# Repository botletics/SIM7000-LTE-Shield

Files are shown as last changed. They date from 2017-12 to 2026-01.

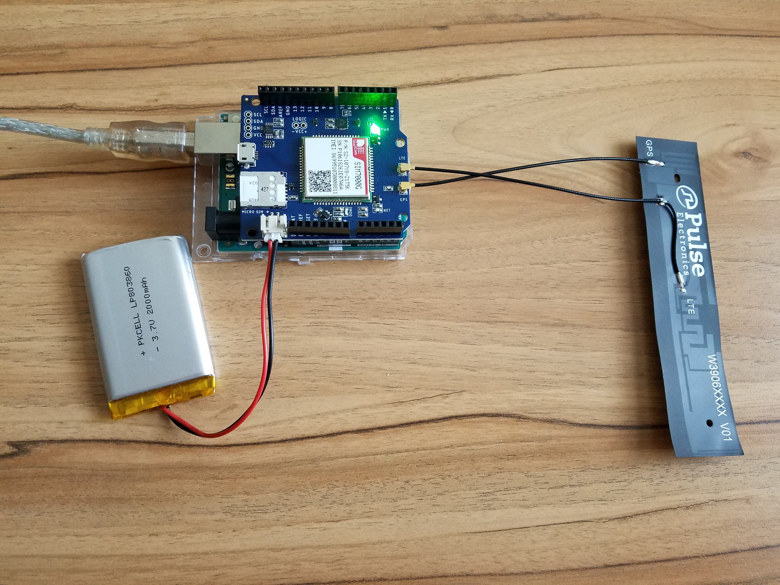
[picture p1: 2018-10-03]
Media/SIM7000 Shield v5 Complete Setup.jpg

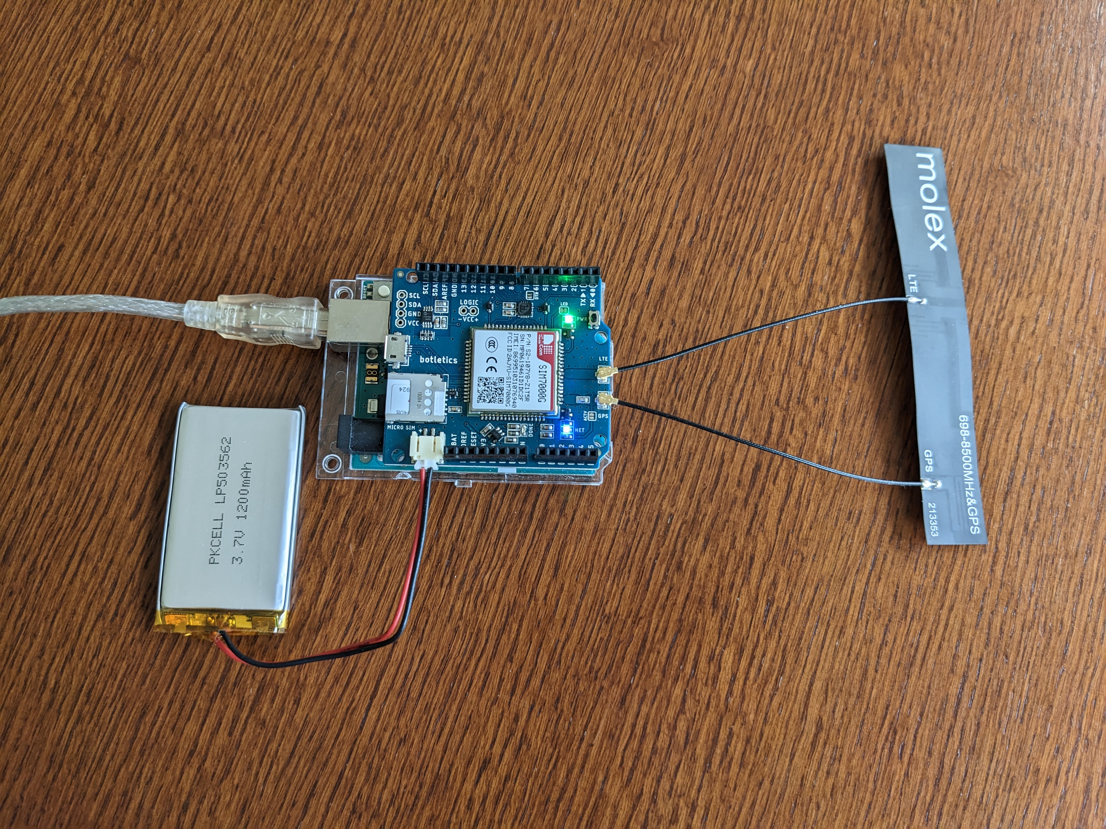
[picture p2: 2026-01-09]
Media/SIM7000 Arduino Assembly v6.jpg

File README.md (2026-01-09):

## Overview
This shield uses SIMCOM's SIM7000-series module, a low-power cellular module that supports LTE CAT-M1 and NB-IoT technology and integrated multi-GNSS (GPS, GLONASS and BeiDou/Compass, Galileo, QZSS standards) for location tracking. The shield also includes a high-accuracy I2C temperature sensor for IoT monitoring applications.

- [Buy shield on Amazon](http://a.co/d/eQ2l2TL)
- [Step-by-step wiki](https://github.com/botletics/SIM7000-LTE-Shield/wiki)
- [Arduino library with example code](https://github.com/botletics/Botletics-SIM7000) 
- [Botletics community forum](https://forum.botletics.com/) 

All PCB design files and hardware are released under the [Creative Commons Attribution Share Alike 4.0 license](https://choosealicense.com/licenses/cc-by-sa-4.0/).

All other software is released under the [GNU General Public License v3.0](https://choosealicense.com/licenses/gpl-3.0/).

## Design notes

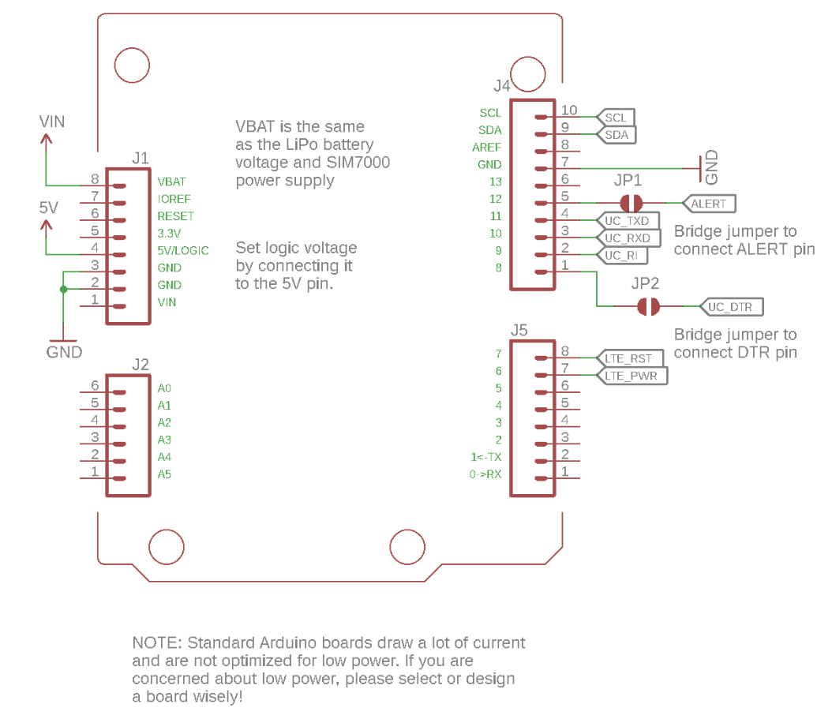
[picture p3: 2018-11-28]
Media/SIM7000 Shield Pinouts v6.PNG

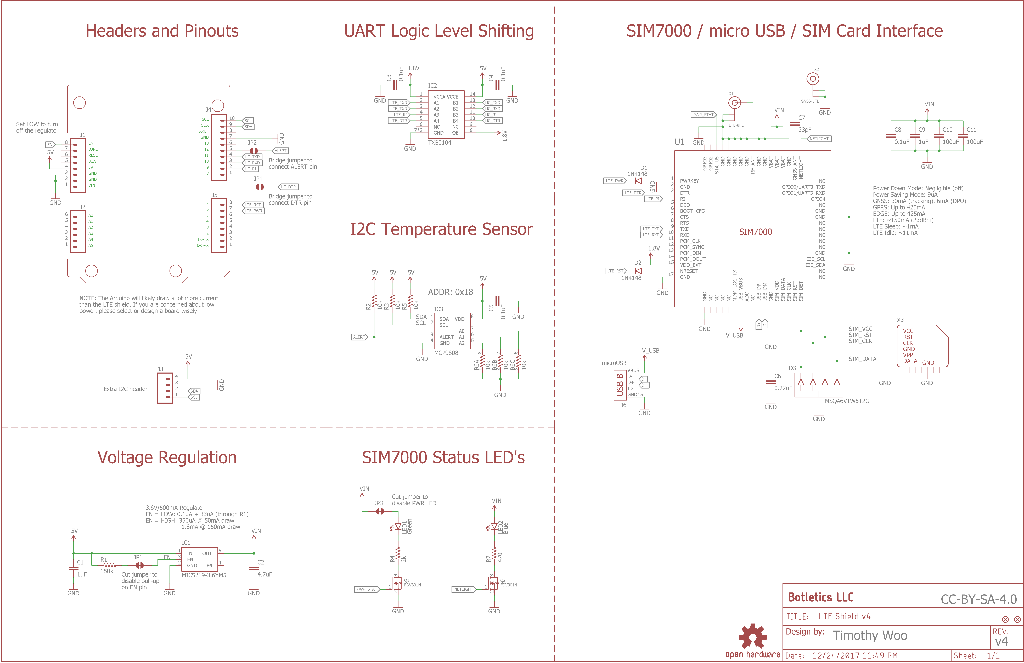
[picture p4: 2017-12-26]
Media/SIM7000 Shield Schematic v4.png

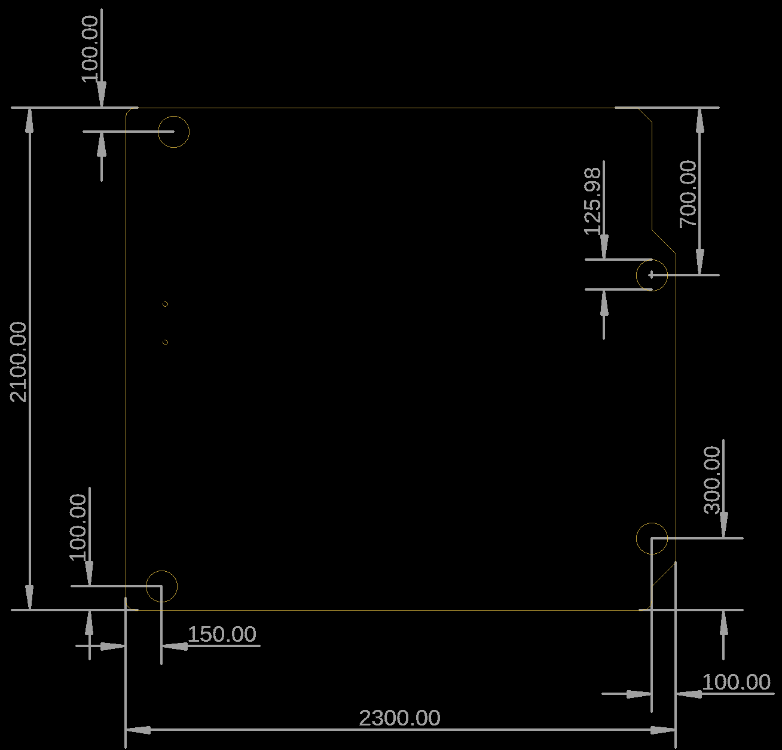
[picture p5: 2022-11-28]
Schematics/Board Dimensions.png

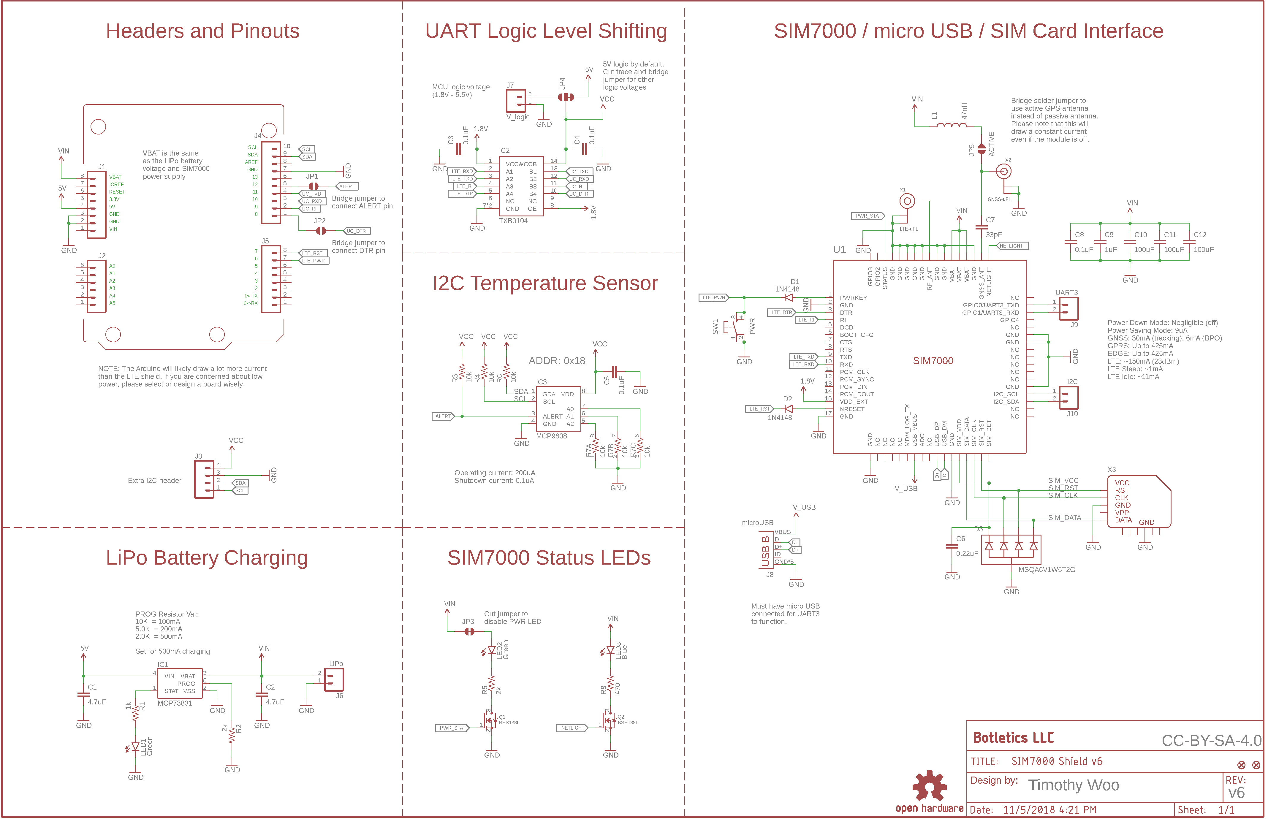
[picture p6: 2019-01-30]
Schematics/SIM7000 Shield Schematic v6.png

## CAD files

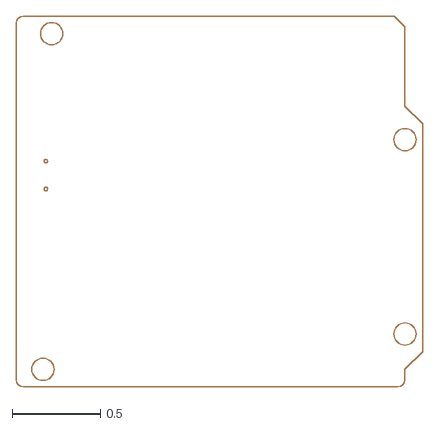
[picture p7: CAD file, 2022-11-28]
Schematics/SIM7000 Shield v6.dxf
2.30 x 2.10

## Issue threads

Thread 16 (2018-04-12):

Add support to upload firmware properly to solve IMEI issue

bengchet, 2018-04-12:
Hi,

First of all I would like to say your project is great, I love it. Here is some experience I did some firmware upgrade and I would like to share it.

I remembered I bought SIM7000E module before June 2017 and the module firmware is not very updated. So many AT command stated in manual can't be used. Been followed your guide on firmware update tool, I found that IMEI on module was missing after firmware upgrade.

To solve this, you will need restore QCN file attached follow the instruction under section **How to update xQCN file if necessary** in _How to update SIM7000 FW version with QPST.pdf_. The QCN file is standard and works for all SIM7000 series. Then run AT+SIMEI=_your IMEI number_. You can find IMEI number on top of SIM7000 module. Hope it helps.

[MDM9206_SIM7000E_P1.02_20180118.xqcn.zip](https://github.com/botletics/SIM7000-LTE-Shield/files/1902242/MDM9206_SIM7000E_P1.02_20180118.xqcn.zip)

** Better to confirm with SIMCOM engineer if the file works for all SIM7000.

botletics, 2018-04-12:
Thanks for your feedback! I will look into this.

gmgaston, 2019-02-27:
While running the IOT_Example provided, it runs down to the point where it tries to get the IMEI and then freezes.   I looked at the Adafruit_FONA.cpp file that is supplied on this github site.  It looks like it is expecting a 15 character IMEI but the IMEI on my Hologram SIM is 19 characters long.  I tried to adjust both the .ino and the .cpp file but still doesn't work.  I might not have done the adjustments correctly.
Any help to get my SIM7000-LTE-Shield working will be appreciated.
Thanks
Greg

adam6806, 2019-02-28:
I just added a ticket before I saw this comment from @gmgaston I'm having the exact same issue. I'm going to see if I can make the adjustment to the code as well but I would definitely appreciate a fix here. It is strange that the LTE demo worked perfectly but the iot example isn't. Wouldn't the both use the same library?

gmgaston, 2019-02-28:
I may have been mistaken about the length of the IMEI. I at first thought the IMEI was the 19 digit number on the hologram SIM card but that is not correct.

I do stand by my comment that I still can't get past where the IOT _Example tries to fetch the IMEI. I just hangs there.
The LTE_Demo does work OK.

Thanks
Greg

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

adam6806, 2019-02-28:
@gmgaston why don't we move this over to my issue then instead of this closed one. I did come to the same conclusion about the imei length. One other thing I noticed is that the lte demo has a reply buffer array and the iot example does not. reply buffer is used in that method. maybe there's something there.

gmgaston, 2019-02-28:
Adam:
OK. I don't know much about the issues blog. I just found it when I did a Google search for botletics/SIM7000-LTE-Shield and IMEI.

I will be spending some time on this in next few days. If I find something I'll let you know ..

Thanks
Greg

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

adam6806, 2019-02-28:
@gmgaston Link to the issue is here. If you find anything please post there. https://github.com/botletics/SIM7000-LTE-Shield/issues/75

botletics, 2019-03-04:
Make sure your board has a LiPo battery connected to it, and with proper polarity (red wire on the left side of the connector when you plug it in). Usually weird characters in serial monitor means there's a power issue.

hasikp1, 2020-06-30:
@botletics do you have the SIM7000C firmware with you? I used the waveshare SIM7000C firmware but it shows as B08SIM7000.
@bengchet I used the method you mentioned and restored a IMEI of SIM7000E it was successfull, but when I used it in the above mentioned SIM7000C firmware shows as B08SIM7000E. Do you have a qcn for SIM7000C

Closed 2018-06-04.

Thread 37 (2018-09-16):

Couldn't find FONA

aggounix, 2018-09-16:
I added the library and I uploaded the library but now I have another issue in the port monitor : Couldn't find FONA
I am using Hologram Sim card

botletics, 2018-09-16:
It's probably because you're using different hardware. Please keep your posts under the same issue and unfortunately I can't help everyone trying to use this library with their own hardware. [Look here if you want the official Botletics SIM7000 shield kit](https://www.botletics.com/products/sim7000-shield)

aggounix, 2018-09-17:
I bought the the same 7000E shield in the tutorial from botletics and using it with your tutorial here:
https://www.hackster.io/botletics/real-time-2g-3g-lte-arduino-gps-tracker-iot-dashboard-01d471
With this library and no other hardware is used here

botletics, 2018-09-17:
The default initialization code doesn't wait for the module to turn on, so you have to press the Arduino's reset button after you see the green PWR LED for the SIM7000 the first time you start it up.

aggounix, 2018-09-22:
I think there is a probleme with the SIM7000 because the PWR LED is never green (the status LED in [Shield pinout.](https://cdn.instructables.com/F4D/3G87/JFIIS97S/F4D3G87JFIIS97S.LARGE.jpg))
May be it is a problem with the SIM7000 shield

botletics, 2018-09-22:
That won't cause a compile error though.

aggounix, 2018-09-22:
this is not a compile error, the code is televersed to arduino and during execution it couldn't find the fona and I think because the shield is not powered up
The Staatus LEd is not working at all

botletics, 2018-09-22:
Please email me at botletics@gmail.com so we can share images more easily.

aggounix, 2018-09-22:
Thanks  a lot, I just sent you the images to your mail

botletics, 2018-09-22:
Thanks. The issue is most likely because you didn't solder the headers onto the board at all, so they're not making connection.

aggounix, 2018-09-22:
How  can I solder the headers to the headers, it seems to me fragile I am afraid to break it, do you have images on how must be done

botletics, 2018-09-22:
Yes, please see [this wiki page](https://github.com/botletics/SIM7000-LTE-Shield/wiki/Assembly)

aggounix, 2018-09-22:
Should I do it with a soldering tool kit like this: https://learn.adafruit.com/adafruit-guide-excellent-soldering/tools

botletics, 2018-09-22:
You just need a soldering iron and solder. There are many options available online, like on Amazon.

aggounix, 2018-10-01:
Great News, I soldered the pins to the shield and I get the status LED turned ON, I tried the IOT_Example and after pressing arduino reset button, I get it work. Iget these message:

FONA is OK
Found SIM7000E (European)
	---> AT+GSN
	<--- xxxxxxxxxxxxxxxxxxx
Module IMEI: xxxxxxxxxxxxxxxxxxx
	---> AT+CGNSPWR?
	<--- +CGNSPWR: 0
	---> AT+CGNSPWR=1
	<--- OK
Turned on GPS!
	---> AT+CIPSHUT
	<--- SHUT OK
	---> AT+SAPBR=0,1
	**<--- ERROR**
Failed to disable GPRS!
	---> AT+CIPSHUT
	<--- SHUT OK
	---> AT+CGATT=1
	<---
Failed to enable GPRS, retrying...
	---> AT+CIPSHUT
	<---
	---> AT+CGATT=1
	<---

Is it normal to get error for enabling GPS and failing enabling GPRS

botletics, 2018-10-01:
Are you using a LiPo battery? Does the green "PWR" LED next to the module ever turn off when you try to enable data? Disabling data and getting an error is OK, but enabling afterwards should work as long as you're connected to the network.

aggounix, 2018-10-01:
I am using the usb connection to power the shield.  The "PWR" LED is always on. In the tutorial it is said the iot code must be able to send gps position to dweet normally. What am I doing wrong to not have the position on dweet

botletics, 2018-10-01:
The USB does not power the shield, as mentioned in the wiki. Please run the LTE_Demo sketch first and make sure you're connected to the network (use "n" command) and that everything else works (GPS, etc). Then you can move on to the IoT_Example sketch.

aggounix, 2018-10-01:
When I use th en command in LTE_Example I get this message:
Network status 2: Not registered (searching)
I am using a hologram sim card

botletics, 2018-10-01:
That would explain why you can't enable data. Please see [this wiki page](https://github.com/botletics/SIM7000-LTE-Shield/wiki/Connecting-to-Network) on getting connected.

JetForce33, 2019-03-04:
Thank you!

mduiop, 2021-03-07:
I am using the SIM7000A module purchased from Amazon in the U.S..  I am attempting to run LTE_Demo on my Arduino Mega 2560.  I have a 3.7v battery connected to the battery terminal.  I am using the provided headers soldered onto the module.  Activated Hologram SIM.  I set my vars as such:

// For SIM7000 shield
#define FONA_PWRKEY 6
#define FONA_RST 7
//#define FONA_DTR 8 // Connect with solder jumper
//#define FONA_RI 9 // Need to enable via AT commands
#define FONA_TX 1 // Microcontroller RX
#define FONA_RX 0 // Microcontroller TX
//#define T_ALERT 12 // Connect with solder jumper

When I run this code on the Arduino with the SIM7000A I get:

. . .
Timeout: No response to AT... last ditch attempt.
	---> AT
	<---
. . .
	---> ATE0
	<---
Couldn't find FONA

botletics, 2021-03-07:
The issue looks like it's because you changed the pin definitions. Please load the unaltered LTE_Demo sketch and see if it works.

mduiop, 2021-03-07:
> The issue looks like it's because you changed the pin definitions. Please load the unaltered LTE_Demo sketch and see if it works. By default the code uses software serial with pins 10 and 11 for UART.

OK, I could have sworn I did, but to "humor you" I decided to do that yet again.  Well, it works now, so thank you very much for the quick reply.  (If you detect sarcasm it is self-deprecating . . . not directed at you . . . mocking myself).

sagarchowdhury, 2021-04-24:
i am also getting the same error couldnt find fona

mduiop, 2021-04-24:
> i am also getting the same error couldnt find fona

Make sure you have reception, and don't change the pin definitions. That worked for me. I used the scripts unaltered and they worked.

sagarchowdhury, 2021-04-24:
> > i am also getting the same error couldnt find fona
>
> Make sure you have reception, and don't change the pin definitions. That worked for me. I used the scripts unaltered and they worked.

yes the the network led light is blinking after every 3 seconds, what i did differently is i used breadboard to connect the header with the module ,and connected each header pin with a jumper wire to the Arduino to simulate it like a shield ,do you think there may be loose connection because i didnt solder the header pins with the module

mduiop, 2021-04-24:
I'm no expert, but yes, that is a big possibility. Solder the header pins
and use it as a shield if you can. Requires a good connection.

On Fri, Apr 23, 2021, 11:03 PM sagar chowdhury ***@***.***>
wrote:

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

sagarchowdhury, 2021-04-24:
> I'm no expert, but yes, that is a big possibility. Solder the header pins and use it as a shield if you can. Requires a good connection.
> […](#)
> On Fri, Apr 23, 2021, 11:03 PM sagar chowdhury ***@***.***> wrote: i am also getting the same error couldnt find fona Make sure you have reception, and don't change the pin definitions. That worked for me. I used the scripts unaltered and they worked. yes the the network led light is blinking after every 3 seconds, what i did differently is i used breadboard to connect the header with the module ,and connected each header pin with a jumper wire to the Arduino to simulate it like a shield ,do you think there may be loose connection because i didnt solder the header pins with the module — You are receiving this because you commented. Reply to this email directly, view it on GitHub <[#37 (comment)](https://github.com/botletics/SIM7000-LTE-Shield/issues/37#issuecomment-826024235)>, or unsubscribe <https://github.com/notifications/unsubscribe-auth/ANFG5KMKQTHNTC2H47AKSGLTKIYGVANCNFSM4FVLNFPQ> .

one strange thing i noticed is i am getting replies at 9600 baud rate in com port but it should ideally be 115200 ,when i am changing to the 115200 i am not finding anything ,the serial monitor is blank

mduiop, 2021-04-24:
Yeah, I'm pretty sure the serial monitor has to be set to the same baud
rate set in the script.

On Fri, Apr 23, 2021, 11:15 PM sagar chowdhury ***@***.***>
wrote:

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

Closed 2018-09-16.

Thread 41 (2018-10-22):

Firmware update failed

robertgrochowski, 2018-10-22:
Hello,

I have installed all the drivers, no unknown devices appear in Windows Device Manager.
I also followed upgrade instructions step by step, checked everything few times but I still can't manage to update due to "ConnectServer failed1, Please repower 1 DUT" error.

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

Thanks in advance

botletics, 2018-10-22:
Hi there,

To aid in assisting you, what hardware are you using? Do you have a 3.7V LiPo battery connected? It may be that your device is shutting off when trying to update. Updating firmware requires a lot of power.

robertgrochowski, 2018-10-22:
Hi,

Thank you for fast reply. To be honest, I use another SIM700E shield (exactly DFRobot Shield NB) but the producer doesn't include information how to upgrade it. Only Your tutorial seems to be suitable.

I power it from power supply (12v through VIN) and the board works like a charm.

I have tried also your 2nd tutorial to upgrade it through QPST Tool but unfornatelly I run into difficulties because I couln't select port from the list (the list was empty). I tried to run as administartor, restart my PC and board as well but that didn't help. Do you have any suggestions?

Thanks in advance.

botletics, 2018-10-22:
Do you have any sort of indication that the module is turning off during the update process, especially right before it says to repower DUT?

botletics, 2018-10-22:
Could you show me a screenshot of what device manager looks like before you do the update? Go through literally each entry in device manager that's related to the SIM7000, right click, update driver, and point it to the drivers folder.

robertgrochowski, 2018-10-22:
Of course, I have done it for every SIM device.

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

botletics, 2018-10-22:
Hmm not sure, sorry.

lutfisan, 2018-11-16:
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

is it solve? i have same problem

robertgrochowski, 2018-11-16:
Unfortunately, no.

royallyovershoot, 2019-11-02:
Hey, @robertgrochowski I know it's more than a year late but I encountered the same exact problem with DFRobot and figured out how to fix it. Feel free to PM me since I this is a Botletics chain :)

robertgrochowski, 2019-11-02:
@royallyovershoot Thanks for letting know. Can you post your solution here? It will help others as well.

royallyovershoot, 2019-11-02:
Ok, there are two test points on the board (TP1 and TP2) shown on the attached snippet of the schematic. Those need to be shorted together during update, so using a soldering iron you can solder two pin headers and use a shunt to short them when you are updating the firmware and then remove the shunts when you're done with the update.

It's important to keep in mind that those two pins must be shunted before powering up the board.
I got to 100% but I got an error that it failed to back-up. But everything is working fine. This was included from the hardware design guide: [here](https://simcom.ee/documents/SIM7000x/SIM7000%20Hardware%20Design_V1.05.pdf)
On Page 20  under "Other interface" -> Boot_CFG it explains it.

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

madatr, 2019-11-19:
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

MAN, YOU ARE A GOD SEND!!!!!
I've been stuck on this for two weeks and was at giving up point.
Thank you for taking up time to share this.
and shame on manufacturers who don't share crucial information like this.

royallyovershoot, 2019-11-19:
@madatr Hah, I'm glad that it helped! It was a dick move from the manufacturers but hope you complete your project with ease now :)

hasikp1, 2019-11-19:
Hi, I have a SIM7000E module bought from aliexpress. It only have 7 pins as output, G-GND,R-RXD,T-TXD,K-PWRKEY,V-VCC,G-GND and S-SLEEP. I tried to update the firmware following the guide provided by @botletics. I also got the "QHSUSB_BULK" in device manager. Does this mean somehow I have to get boot_cfg and VDD_EXT shorted based on steps provided by @royallyovershoot. Is there any other alternatives?

madatr, 2019-11-20:
well... I can't tell you what to do exactly. The board i'm using has a USB connector provided with necessary hardware to facilitate that, the error/issue I had is that the update software wouldn't be able to switch the board to download mode so I had to force it using @royallyovershoot instructions.
I would recommend that you make sure that your board can communicate with the PC correctly first as the issue might be from that end.
btw, my board does not have the boot_cfg and vdd_ext as well, i just shorted the pins on the chip using a wire and had someone use the software to update it:
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

KerryRJ, 2020-06-11:
I have a waveshare NBT-IoT hat. I also got stuck at "waiting switch to download mode" and the QHSUSB_BULK device appeared in device manager. I just updated the driver in device manager from https://www.waveshare.com/wiki/File:SIM7X00-Driver.7z and the update process immediately continued.

hasikp1, 2020-06-15:
@madatr Are you using this module
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

semorem, 2020-09-16:
> I have a waveshare NBT-IoT hat. I also got stuck at "waiting switch to download mode" and the QHSUSB_BULK device appeared in device manager. I just updated the driver in device manager from https://www.waveshare.com/wiki/File:SIM7X00-Driver.7z and the update process immediately continued.

@KerryRJ hello there, i have the same issue that you did with the same hardware, but i already have the lastest dirvers installed. Did you just update the drivers? Did you do it during the firmware's update?

KerryRJ, 2020-09-16:
I updated the driver during the firmware update.

Kind Regards

Kerry Jones
Owning Member

Info-Overdrive cc
[IO Drive square logo - blue - small]

m. +27(0)612403717
e. kerry@iodrive.co.za<mailto:kerry@iodrive.co.za>
a. F3 Chief Mhlabunzima Rd., Pietermaritzburg, 3201

Website<http://www.iodrive.co.za/>        Email<mailto:kerry@iodrive.co.za>            IM<sip:kerry@iodrive.co.za>

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

semorem, 2020-09-16:
Thanks dude! It seems to be working!!!

BuiHao1996, 2020-10-30:
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

Could you send me your software to upload SIM 7600CE ?

MaffooClock, 2021-01-27:
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

When I got to this, I simply installed the driver (from the same folder as all the other drivers), and as soon as it finished, QDL resumed automatically.

VeselaHouba, 2021-04-16:
I know this thread is closed, but just for reference:
Using waveshare sim7000E

1. Blew off dust of my old Windows Laptop
1. Plugged the module to USB, didn't see any issues with power consumption
1. Installed drivers as described in https://github.com/botletics/SIM7000-LTE-Shield/wiki/USB-Drivers
1. Following upgrade guide https://github.com/botletics/SIM7000-LTE-Shield/wiki/Updating-Firmware
1. Upgrade hanged on something like "Waiting to switch to download mode"
1. Opened device manager, installed latest driver from https://www.waveshare.com/wiki/File:SIM7X00-Driver.7z
1. Update tool picked-up by itself and continued the installation until finish

kjm1102, 2023-12-29:
More than 2 years after the last post, I might get lucky?
I've got a 7080G with 1951B05sim7080 firmware that doesn't work too well but the downloader wants to load 1951B04sim7080 which is even older.
I'd like to upgrade it to 1951B07sim7080 that runs great in another 7080G but I can't figure out how to copy it from the modem it's in.
So I'm looking for a link to where I might get some 1951B07sim7080 firmware

eisaev, 2024-01-02:
@kjm1102 Have you tried this?
https://github.com/Xinyuan-LilyGO/LilyGo-T-PCIE/tree/master/update_simxxxx_firmware/1951B08SIM7080

kjm1102, 2024-01-02:
tnx for the links. I grabbed the 3 files that this wretched flasher I got from waveshare says it needs & copied them to a folder on an E drive to match the byzantine path it needs (there seems to be no way to edit the path) but the usual story, "computer says no". Can you see what I've missed from the attached? I'm new to modem flashing.
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

eisaev, 2024-01-03:
> tnx for the links. I grabbed the 3 files that this wretched flasher I got from waveshare says it needs & copied them to a folder on an E drive to match the byzantine path it needs (there seems to be no way to edit the path) but the usual story, "computer says no". Can you see what I've missed from the attached? I'm new to modem flashing. ![noexist](https://private-user-images.githubusercontent.com/92007731/293807827-1b56f12e-0dc4-461c-9699-e51dee20c9a8.jpg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)

The flasher expects that there will be more subfolders in the path. Increase the size of the flasher window to see the full path and try to create the required folder structure.

kjm1102, 2024-01-03:
tnx Evgeniy.  I finally got the firmware folders where the updater tool expects to find them.
1) At the beginning device manager shows 3 comports:
    SimTech HS-USB AT Port 9205 (COM27)
    SimTech HS-USB Diagnostics 9205 (COM29)
    Simtech HS-USB NMEA 9205 (COM28)
2) The tool starts on com 29, reads the imei & does a few other things then swaps to COM27
3) There is a USB disconnect & the 3 comports ABOVE vanish to be replaced Qualcom HS-USBQDLoader 9008 (com30)
4) The tool reconnects on COM30 but timesout waiting for prog_firehose_nand.elf which is definitely present in the folder
Any thoughts on what I could try next?

Closed 2018-10-22.

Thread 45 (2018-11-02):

Intermittent PWR issue

airy52, 2018-11-02:
The board seems to intermittently reset the power and the PWR LED on your sim7000A board board goes off. I am sometimes able to get the chip to connect to the verizon hologram network and issues the n or 1 command in the LTE_demo example. Sometimes I get ctreg 0,2 which is searching. But eventually the PWR LED resets and I am unable to get any further responses from AT commands until I hit the reset button on the arduino mega 2650 board to establish a connection with it again. When it connects to the network it seems to be pretty stable for a while, until I issue the G command for gprs. It then gets to the SAPBR command, or sometimes as far as this:
---> AT+SAPBR=1,1
	<--- OK
	---> AT+CIICR
	<--- +PDP: DEACT
But then the power resets and I am stuck unable to get a response again. When I first tried this a week ago I was able to reach the internet once or twice, after many failed attempts. I did not edit any of the code. I'm connected by USB power. The antenna is connected correctly and I have good signal. Any ideas?

botletics, 2018-11-02:
Sounds like you do not have a 3.7V LiPo battery, which is required. Please try that and it should work like a charm :)

Closed 2018-11-02.

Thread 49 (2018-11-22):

No PPP on UART with B05

Redferne, 2018-11-22:
Hi,

Just tried the B05 firmware but couldn't setup PPP over UART anymore:
```
-> AT+CGREG?
<- OK
-> AT+CGATT?
<- ..+CGATT: 1....OK..
-> AT+CPSI?.
<- +CPSI: LTE CAT-M1,Online,240-XX,0x0086,7681025,0,EUTRAN-BAND1,1925,2,2,0,0,125,0 OK
-> AT+CGPADDR.
<-  +CGPADDR: 1,10.41.136.51 OK
-> AT+CGNAPN.
<- +CGNAPN: 1,"xxx.com.xx" OK
-> ATD*99***1#.
<- ERROR
```

I had to downgrade to B03 again:
```
-> ATD*99***1#.
<- CONNECT 150000000
```
And PPP over UART works fine again. Any ideas?

botletics, 2018-11-22:
I'm assuming you're using SIM7000E? Sorry, I really have no idea because I only use SIM7000A and SIM7000G here in the US.

supersjimmie, 2018-12-11:
I  have heard there is a B06 firmware coming (for my sim7000e).
They gave an early version to me because an issue with the NMEA port, but that caused other issues. So you might wait or even ask Waveshare for the B06 firmware release.

korseby, 2019-02-18:
Have you found a solution yet?

I have the same problem using the Waveshare HAT (https://www.waveshare.com/wiki/SIM7000E_NB-IoT_HAT).

I've updated to the B06 Firmware from their website but getting the same error when using ATD.

supersjimmie, 2019-02-18:
This was the reply then:
If you send AT command to get GPS data via USB interface, USB interface will be hang-up as soon as GPS is enabled, because GPS data is outputed from USB port by default. We doubt that the problem you face is caused by this reason. Did you try to change the NMEA output?

xmichaelx, 2019-03-17:
@korseby @supersjimmie Same issue here. Any good news on this? I've managed to get GPS working and establish TCP connection using sample programs  but with ppp no luck so far.

I'm using these [instructions](https://www.waveshare.com/wiki/SIM7000E_NB-IoT_HAT). Do you have any other recommendation for similar board that works better with ppp?

korseby, 2019-03-18:
As far as I understand it, linux handles the IoT devices using a different protocol. I tried to play around with `usb_modeswitch` and `modprobe usbserial` and tried to bring linux to recognize the Waveshare board as `wwan` interface (using the IoT protocols), but without luck so far. In theory, the `ModemManager` is supposed to do all that, but it seems to be broken in the current Raspbian release.

Below is what I have tried as far as I remember it. As many of the config option have changed because Raspbian switched to `systemd` I do not know anymore how to properly configure network interfaces with terminal commands... That s****s and there is no proper documentation around how the commands are with IoT devices ...

Editing /etc/network/interface.d/wwan0 (this has become obsolete) ...
```
iface wwan0 inet dhcp
   wwan_apn  "APN"
```

Set the APN and bring up the IoT connection manually (you can also do this using minicom -D /dev/ttyS0) ...
```
echo -ne 'AT^NDISDUP=1,1,"APN"\n\r' > /dev/ttyS0
echo -ne 'AT+CIPCSGP=1,"APN","",""' > /dev/ttyS0
echo -ne 'AT+CGDCONT=1,"IP","APN"' > /dev/ttyS0
echo -ne 'AT+CNACT=1' > /dev/ttyS0
echo -ne 'AT+CSTT="APN"\n\r' > /dev/ttyS0
echo -ne 'AT+CIICR\n\r' > /dev/ttyS0
```

Bringing up wwan0 manually ...
```
ifconfig wwan0 up
dhclient wwan0
netstat -rn
ip route add default via x.x.x.x dev wwan0
```

Playing around with ModemManager and/or the CLI ...
```
mmcli -L
nmcli c add type gsm wwan0 /dev/usbS0 con-name APN apn APN
nmcli r wwan0 on
```

Maybe you can figure it out better than I do :)

Some other people had similar problems ...
https://blog.soracom.io/beginners-guide-to-iot-cellular-connectivity-on-raspberry-pi-and-linux-devices-55d4f7489adf
https://docs.ubuntu.com/core/en/stacks/network/network-manager/docs/configure-cellular-connections
https://www.linuxquestions.org/questions/linux-wireless-networking-41/help-using-3g-usb-dongle-through-wwan-interface-rather-than-ppp-4175537653/

Good luck.

xmichaelx, 2019-03-18:
@korseby Thank you, at the very least you've given me hope :)

xmichaelx, 2019-03-18:
I've  tried using *wvdial* with following config (SIM7000 plugged in via USB):
```
[Dialer Defaults]
Init1 = ATZ
Init2 = ATQ0 V1 E1 S0=0 &C1 &D2
Init3 = AT+CGDCONT=1,"IP","plus"
Modem Type = Analog Modem
ISDN = 0
Phone = *99#
Modem = /dev/ttyUSB2
Username = blank
Password = blank
Baud = 9600
```

and the output from wvdial:

```
--> WvDial: Internet dialer version 1.61
--> Cannot set information for serial port.
--> Initializing modem.
--> Sending: ATZ
OK
--> Sending: ATQ0 V1 E1 S0=0 &C1 &D2
ATQ0 V1 E1 S0=0 &C1 &D2
OK
--> Sending: AT+CGDCONT=1,"IP","plus"
AT+CGDCONT=1,"IP","plus"
OK
--> Modem initialized.
--> Sending: ATDT*99#
--> Waiting for carrier.
ATDT*99#
CONNECT 150000000
--> Carrier detected.  Waiting for prompt.

--> Connected, but carrier signal lost!  Retrying...
--> Sending: ATDT*99#
--> Waiting for carrier.
--> Timed out while dialing.  Trying again.
--> Sending: ATDT*99#
--> Waiting for carrier.

```

and LED on my SIM7000E-NB-IoT-HAT starts starts repeatedly flashing as if the device stoppped responding and indeed that's what it looks like.

Reissuing wvdial gives:

```
--> WvDial: Internet dialer version 1.61
--> Cannot set information for serial port.
--> Initializing modem.
--> Sending: ATZ
--> Sending: ATQ0
--> Re-Sending: ATZ
--> Modem not responding.
```

so it looks like the serial port stopped responding altogether.

I'm kinda disappointed - I've sort of managed to get GPS signal when hat is connected to GPIO pins and also managed to get the samples working, but getting working ppp/wwan0 seems to be impossible.

Anyways @korseby thanks for help. Do you have any recommendations for alternative that you know works well on raspberry?

qsun, 2019-07-22:
It looks like I've same issue with B05 firmware on SIM7000E, but I could not confirm it's working with B03.

korseby, 2019-07-22:
Latest waveshare firmware includes some additions, but could not read about fixes... It could be worth a try though.

https://www.waveshare.com/w/upload/6/60/NDA_SIM7000E_Firmware_Release_Note.pdf

qsun, 2019-07-23:
@korseby

Thank you very much for your reply, and I can confirm B08 firmware is working fine.

```
AT+GMR
Revision:1351B08SIM7000E

OK
AT+CGREG?
+CGREG: 0,2

OK
AT+CGREG?
+CGREG: 0,1

OK
AT+CPSI?
+CPSI: LTE CAT-M1,Online

OK
AT+CGPADDR
+CGPADDR: 1,10.118.51.20
+CGPADDR: 13,0.0.0.0

OK
AT+CGNAPN
+CGNAPN: 1,"telstra.m2m"

OK
ATD*99***1#
CONNECT 150000000
```

qsun, 2019-07-23:
@korseby

Thank you very much for your reply, and I can confirm B08 firmware is working fine.

```
AT+GMR
Revision:1351B08SIM7000E

OK
AT+CGREG?
+CGREG: 0,2

OK
AT+CGREG?
+CGREG: 0,1

OK
AT+CPSI?
+CPSI: LTE CAT-M1,Online

OK
AT+CGPADDR
+CGPADDR: ~~~
+CGPADDR: ~~~
OK
AT+CGNAPN
+CGNAPN: 1,"telstra.m2m"

OK
ATD*99***1#
CONNECT 150000000
```

botletics, 2019-07-23:
I guess I can close this now?

Closed 2019-07-23.

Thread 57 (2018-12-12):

Commands echo back instead of OK

supersjimmie, 2018-12-12:
At several different point, sometimes the program goes into a loop, because the sim7000 starts to repeat the commands instead of replying with OK.

This happens at more places, during GPS, during Connect to cell, and more.
Looks like:
```
Failed to get GPS location, retrying...
	---> AT+CGNSINF
	<--- AT+CGNSINF
Failed to get GPS location, retrying...
	---> AT+CGNSINF
	<--- AT+CGNSINF
```

Or:
```
Failed to connect to cell network, retrying...
	---> AT+CGREG?
	<--- AT+CGREG?
Network status 0: Not registered
Failed to connect to cell network, retrying...
	---> AT+CGREG?
	<--- AT+CGREG?
```
I tried to flush the fonaSS, send an extra AT, wait a while, I cannot find why and I cannot find how to get out of this strange state...

botletics, 2018-12-12:
Did you set **ATE1** which enables echo? For example, if you were trying to send AT commands via USB and set ATE1 so that you can see the stuff you're typing.

botletics, 2018-12-12:
To disable, set **ATE0** which should also be set during module initialization in the LTE_Demo code.

supersjimmie, 2018-12-12:
Yes it does ATE0 at the beginning.
Here's some more:

```
Attempting to open comm with ATs
	---> AT
	<--- OK
	---> ATE0
	<--- OK
	---> ATE0
	<--- OK
	---> ATI
	<--- SIM7000E R1351

OK

	---> AT+CPMS="SM","SM","SM"
	<--- +CPMS: 0,0,0,0,0,0
FONA is OK
Found SIM7000E (European)
	---> AT+GSN
	<--- 8652340xxxx
Module IMEI: 8652340xxxx
	---> AT+CFUN=1
	<--- OK
	---> AT+CGDCONT=1,"IP","cdp.iot.t-mobile.nl"
	<--- OK
	---> AT+CGREG?
	<--- +CGREG: 0,5
Network status 5: Registered roaming
Connected to cell network!
	---> AT+CGNSPWR=1
	<--- OK
Turned on GPS!
	---> AT+CGNSINF
	<---
Failed to get GPS location, retrying...
	---> AT+CGNSINF
	<--- +CFUN: 1
Failed to get GPS location, retrying...
	---> AT+CGNSINF
	<--- AT+CGNSINF
Failed to get GPS location, retrying...
	---> AT+CGNSINF
	<--- AT+CGNSINF
```

As you can see, there is also a strange thing happening here:
```
---> AT+CGNSINF
	<--- +CFUN: 1
```
Like it comes back with something from an earlier command.
Then it starts to malfunction...

botletics, 2018-12-12:
Looks like your shield is powering off. Messages like "+CFUN: 1" are usually displayed shortly after it boots up. Please make sure you are using a 3.7V LiPo battery with the shield.

supersjimmie, 2018-12-12:
I have a newer version of the shield, it lacks things like the PWR push button and also the possibility to add the LiPo. When I asked them about it, Waveshare told me that I don't need that.... (looking at the PCB, there is no regulator for the LiPo too)

It works fine about 9 out of 10 times.

botletics, 2018-12-12:
Newer version? The newest version of the Botletics SIM7000 shield has a LiPo battery connector. If you're using something else that sorry, I don't know.

botletics, 2018-12-12:
Sounds like Waveshare didn't fully test their product then. From what you're experiencing, the module is definitely shutting down. If there's a power indicator LED you should be able to see it shut down. Also, try enabling GPS. I think the module will most certainly shut off because GPS draws another 30mA of current.

supersjimmie, 2018-12-12:
LOL, they've also changed the Power-LED. It's always on, regardless of the actual state of the module...
(they also changed the PWR-pin behavior, but I am able to do the power down, while the LED stays on)
I guess the only way to save some extra current during power down, is to kick that LED off the PCB...
They only way so actually see the power down is via the current draw and the activity LED that really stops blinking. (and the module stops accepting AT commands when I test it)

There is a large 1000uF capacitor on the board, which they say should fix it.
I will try to add an additional tantalum capacitor, which is also very helpful with power-peaking modules likes esp8266's. (tantal's are better for this kind of stabilization)

But just to clarify things a little bit, this is actually not exactly the arduino shield that you use, it's really a module made for the raspberry pi. It's had the same features (like the powerbutton) in the recent past, but because some people had trouble powering it on, they decided to change it.  I had very recent contact with them by e-mail about several of those changes and some issues with the B05 firmware.
They just keep saying that "The SIM7000E is updated", every time I complain.

botletics, 2018-12-12:
Yea I understand you're using the Waveshare Raspberry Pi HAT instead of the shield I created (the Botletics one). Sorry, not much I can do to help there lol. I'm a firm believer that product support should come from the people selling it  :)

supersjimmie, 2018-12-13:
Sure, now we know that it's caused by the lack of lipo support, it's up to the sellers.
But you helped me a lot by finding out that the device was restarting, before that I had no clue...

Fredovsky, 2019-02-13:
@supersjimmie did you manage to solve/identify the issue ? I got the exact same problem, AT response is either : empty; echoes the command; or rarely I have the odd +CFUN: 1. I'm powering up through a separate supply able to handle high load so I don't think power is an issue here.

I know this is not related to Botletics as I'm using the Waveshare piHat board, but curious if others have resolved this problem.

Thanks

supersjimmie, 2019-02-13:
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

@Fredovsky
After a lot of mails, I got the message that "the engineer went on holiday", then nothing... That was about a month ago. I think I will send them a mail to ask if the engineer ever came back.

supersjimmie, 2019-02-14:
@Fredovsky  they now replied that it is solved in firmware: https://www.waveshare.com/wiki/File:1351B06SIM7000E.rar
But I told them last december that I already use that. Perhaps you can check to be sure?

Fredovsky, 2019-02-16:
Thanks I'll try again next week if I can flash the new firmware but last I tried the QPST tool was returning a "DUT 1" (not sure) error. I'll let you know ! Thanks.

Fredovsky, 2019-02-18:
Ok so I updated to the B06 firmware. Problem remains the same. I noticed I don't have any problems when I type the AT commands manually through serial on the Sim7000 USB port (using Putty for exemple).

When using the Arduino and the Fona library, it starts echoing or giving blank replies after 5 or 6 commands...

botletics, 2019-02-24:
Mhmm sorry I'm not sure what is happening. It should find it and communicate right away.

Closed 2018-12-12.

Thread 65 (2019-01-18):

Connecting to hardware serial

ammarqs, 2019-01-18:
Timothy,

I am using the arduino mega and noticed that to use the tcpsend, it is better to use the hardware serial for better baud rates. To set up the hardware serial, please confirm the following changes to the program.

1. Remove all softwareSerial fonass function definitions.
2. in the modulesetup function, change the fonass to Serial3 (or whatever serial port the system is connected to)
3. Change the wiring from D10 to 15 on mega, and D11 to 14 on mega.

botletics, 2019-01-18:
With Arduino Mega if you change the pins from the default D10/D11 software serial pins, the shield won't be directly plug-in compatible.

I am aware of hardware serial allowing faster baud rates, and this is mentioned in a couple places in the Github wiki as well. However, I've had no issues with 9600 baud rate on software serial and it's good enough for most people's applications.

ammarqs, 2019-01-18:
Its ok if its not direct plugin compatible. We will be designing our own controller board to fit this shield.
So the pins D10/D11 are software serial on the shield? it wont work if i connect the D10 to 15 and D11 to 14 on mega. ?

Right, it is. but when trying to send a small image over through the tcpsend function, it takes more than 30secs to a minute to send a 5kb image.

I changed the program to this, and it says couldn't connect:
`Serial.begin(115200);
 Serial3.begin(115200); // Default SIM7000 shield baud rate
  if (! fona.begin(Serial3)) {
    Serial.println(F("Couldn't find FONA"));
    while(1); // Don't proceed if it couldn't find the device
  }
`
It returns back could not find FONA.

botletics, 2019-01-18:
Check out lines 77-89 of the [LTE_Demo sketch](https://github.com/botletics/SIM7000-LTE-Shield/blob/master/Code/examples/LTE_Demo/LTE_Demo.ino)

botletics, 2019-01-18:
[And this](https://github.com/botletics/SIM7000-LTE-Shield/wiki/Pinouts#hardware-serial-note)

botletics, 2019-01-18:
For the code, the [SAMD_LTE_Demo sketch](https://github.com/botletics/SIM7000-LTE-Shield/blob/master/Code/examples/SAMD_LTE_Demo/SAMD_LTE_Demo.ino) will be particularly helpful. It uses hardware serial.

ammarqs, 2019-01-18:
Thank you. that helped. But i am still getting the same couldnt connect error:

`

// Hardware serial is also possible!
HardwareSerial *fonaSerial = &Serial3;

void setup(){
  Serial.begin(115200);
 powerOn(); // Power on the module
  moduleSetup();

void moduleSetup() {
  // Note: The SIM7000A baud rate seems to reset after being power cycled (SIMCom firmware thing)
  // SIM7000 takes about 3s to turn on but SIM7500 takes about 15s
  // Press reset button if the module is still turning on and the board doesn't find it.
  // When the module is on it should communicate right after pressing reset
  Serial3.begin(115200); // Default SIM7000 shield baud rate
 // fonaSerial->begin(115200);
 // Serial.println(F("Configuring to 115200 baud"));
 // Serial3.println("AT+IPR=115200"); // Set baud rate
 // delay(100); // Short pause to let the command run
 // Serial3.begin(115200);
  if (! fona.begin(*fonaSerial)) {
    Serial.println(F("Couldn't find FONA"));
    while(1); // Don't proceed if it couldn't find the device
  }
`
any comments?

botletics, 2019-01-18:
Pin 14 on the Mega should be connected with pin 11 on the shield, and pin 15 on the Mega should go to pin 10 on the shield.

botletics, 2019-01-18:
And get rid of "Serial3.begin(115200)" because you don't need it. What you need is

```
// Communicate with SIM7000 module at with hardware serial
// With hardware serial there's no need to change baud rate
fonaSerial->begin(115200); // Default SIM7000 baud rate

if (! fona.begin(*fonaSerial)) {
  Serial.println(F("Couldn't find SIM7000"));
  while (1); // Don't proceed if it couldn't find the device
}
```

If you just follow the example code it will work. Sorry, but I'm spending a lot of time helping people with this kind of stuff and it adds up.

ammarqs, 2019-01-18:
no you are right. I tried that to. If you look in my code, i commented that because it didnt work.

botletics, 2019-01-18:
Is your shield even turning on? Check the green PWR LED and make sure you have a 3.7V LiPo battery connected with the right polarity (with red wire on the left side of the connector), etc.

ammarqs, 2019-01-18:
yes. If i run my Software serial its runs perfectly. no complains other than slower speeds. That is why i am trying to move on to hardware serial. I changed the program and pins to back to what it was, and it runs fine.

botletics, 2019-01-18:
Since your module is probably at 9600 baud rate, try sending the command AT+IPR=9600 to the module first, then run the code I pasted above and it should work.

ammarqs, 2019-01-18:
i did reset the module to revert any changes in baud rates made previously.
I will try what you said regardless.

botletics, 2019-01-18:
Sorry, I meant AT+IPR=115200 to set it back to 115200 so that it will work with hardware serial.

ammarqs, 2019-01-18:
Serial3.println(" AT+IPR=115200"); RIGHT?

ammarqs, 2019-01-18:
no luck. :(

botletics, 2019-01-18:
That won't do anything because Serial3 is set to 115200, and if your module is at 9600 it won't even receive the command. So what you should do is either run the LTE_Demo sketch with software serial and use the "S" command according to [this wiki page](https://github.com/botletics/SIM7000-LTE-Shield/wiki/Testing-AT-Commands) to send AT commands via serial monitor, or you plug in the micro USB to the shield directly and send the command via a serial terminal like PuTTy by following [these instructions](https://github.com/botletics/SIM7000-LTE-Shield/wiki/USB-Drivers)

ammarqs, 2019-01-18:
so i have to connect it back to software serial and run the command using the 'S' function to set it at 115200 and then configure the hardware serial again and try running. Right. Just trying to get it right so that i dont blow up my module.

botletics, 2019-01-18:
Correct, so two options:
* Connect it back to software serial wiring
* Run LTE_Demo with software serial
* Use the "S" command and send "AT+IPR=115200"
* Then use hardware serial wiring and baud rate of 115200

OR (easiest method):
* Plug in USB to the shield directly and send AT+IPR=115200

ammarqs, 2019-01-18:
Done. Now it works. Thank you.

ammarqs, 2019-01-18:
This is very nice. :+1:
The baud rate changed the game here. less than 14 secs to send the image out. Now i am going to try and go faster. Under 10sec would be ideal for our application. but then again, this is only a 5kb file.
Would you mind telling me the max SAFE baud rate for the sim7000 module?

botletics, 2019-01-18:
I actually haven't tested the max baud rate for hardware serial. I suppose it depends on the microcontroller itself so I didn't bother. Don't be shy, it won't blow up anything. Feel free to try 912600. According to the AT command manual the SIM7000 can handle up to a baud rate of 4000000.

That being said, I read [from this random article I just googled](https://copperhilltech.com/blog/rs232-to-usb-converter-with-arduino-due-or-mega-2560/) that:

> The additional three serial ports on the Arduino Due and Arduino Mega 2560 run only reliably up to 115200 baud. A baud rate of 230400 is possible but you have to deal with random data loss.

ammarqs, 2019-01-18:
yes thats exactly what i read. So apparently i am limited to only 115200 baud rate. i tried doing a 55kb picture, it took almost 3 minutes to completely receive the file data on the server.

botletics, 2019-01-18:
Use the USB method to send AT commands via USB. With USB you can connect at 9600 or almost any baud rate you'd like.

ammarqs, 2019-01-19:
I had to go in detail with the baud rate setting to match both arduino and sim7000 module.
And according to the atmega2560 datasheet, it can safely operate upto 1M bps at 16Mhz.  But sim7000 has different values.
The values that match for both above 115200 is only 230400, nothing above that would match both the controller and the sim7000, so i guess i can only go upto 230400.
I havent tried this yet but in theory it seems legit.

Closed 2019-01-18.

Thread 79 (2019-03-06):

Can't enable GPRS

noratx, 2019-03-06:
Hi!

I have tried the botletics Sim7000E shield now for a few days and I am quite happy about it.
However, i seem to be able to enable most of the available services, except for GPRS.
No matter what I do, it just won't work.
I have double checked with my operator and the APN I am using is correct.

// Set modem to full functionality
  fona.setFunctionality(1); // AT+CFUN=1
  fona.setNetworkSettings(F("internet.tele2.se")); // For Tele2/Comviq card
  fona.setPreferredMode(2); // Use GSM only since NB-IOT/LTE CAT-M is not available!
  fona.enableGPRS(false);

    //Enable GPS
    while(!fona.enableGPS(true))
    {
      Serial.println(F("Failed to turn on GPS, retrying..."));
      delay(2000); // Retry every 2 seconds
    }
    Serial.println(F("GPS turned on!"));
    while (!fona.enableGPRS(true))
    {
      Serial.println(F("Failed to enable GPRS, retrying..."));
      delay(2000); // Retry every 2 seconds!
    }
    Serial.println(F("Enabled GPRS"));

Gives error:

03:52:38.529 -> 	---> AT+CIPSHUT
03:52:38.598 -> 	<--- SHUT OK
03:52:38.633 -> 	---> AT+CGATT=1
03:52:38.666 -> 	<--- OK
03:52:38.734 -> 	---> AT+SAPBR=3,1,"CONTYPE","GPRS"
03:52:38.801 -> 	<--- OK
03:52:39.039 -> 	---> AT+SAPBR=3,1,"APN","internet.tele2.se"
03:52:39.143 -> 	<--- OK
03:52:39.244 -> 	---> AT+CSTT="internet.tele2.se"
03:52:49.555 -> 	<--- RZR
03:52:49.555 -> Failed to enable GPRS, retrying...

I don't want to put all of my code here (beause of it's length),
But it is pretty much the same as the examples (except I removed things that is not needed for me).

What could be wrong?

Best regards
/Rickard

edit: After this post, I actually tried my neighbours simcard which is from another operator...
Same thing, can't enable GPRS, so atleast i know it's not an sim/operator error...
Question is, what could the error be?

botletics, 2019-03-11:
Perhaps your SIM card doesn't support 2G in addition to NB-IoT or LTE CAT-M?

Ghangus, 2019-06-02:
Did you ever find a solution to this issue? I have the same issue right now but with telia.

noratx, 2019-06-02:
Yes,

I found it was my LiPo battery that was faulty and needed to be replaced.

Ceck the battery condition and recharge/replace.

I took a battery from annold samsung phone and soldered some cables to the
battery terminals.
So now I got a 3.7v 2600 MAh battery instead :)

However, I have more or less left the project due to my limited programming
skills.

I cant make the code small enough :/
So I bought an adafruit fona 808 instead for my Rpi zero w, since I never
managed to hook the botletics shield up with the Rpi. :)

/Rickard

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

noratx, 2019-06-02:
And oh, by the way!
It works with bothe Telia, Tele2/Comviq and Hallon/tre in sweden.

Atleast för 2G.
Telia does have support for NB-IoT, BUT, they ONLY sell NB-IoT simcards to
companies :/

/Rickard

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

Closed 2019-06-10.

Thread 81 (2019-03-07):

SMS not sending and hologram.io sms text to device shows nothing

BusTrackerPSU, 2019-03-07:
Setup: Arduino Uno board with the Bothletics Sim7000a shield on top with a LiPo 3.7V 2000mah battery connected as well as the USB plugged into the UNO to the computer,

We are using LTE_Demo example code with a hologram sim card.
Activated the sim card and It is connected Successfully to Verizon IoT network using the Hologram simcard, when on the serial monitor typing "s" to send a SMS message to a phone number in the US and we are located in the US. it says Failed.

We also went on the Hologram.io and send a SMS to the device and it just doesn't receive.
when we press "G"it says everything is okay APN is hologram everything is correct.

I saw that Verizon had a +88 code for outgoing SMS. not sure if its being blocked. Any Ideas?

I can give you more information if you need.

BusTrackerPSU, 2019-03-07:
We got it working after connection to AT&T so that is the issue.

Can we route the sms to use data only or will it charge as a sms as well?

botletics, 2019-03-11:
Yep you can route it: https://github.com/botletics/SIM7000-LTE-Shield/wiki/SMS-Messages#hologram-sms-route

botletics, 2019-03-11:
What you can do is send SMS to Hologram then have Hologram route it, either as SMS or other data form.

Closed 2019-03-11.

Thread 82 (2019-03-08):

Win 10 USB Drive

jinzhang080, 2019-03-08:
I am trying to install USB Drive on my Laptop. But after I plug in the shield, I cannot see it's name in the Device Manager. (the shield is on)

jinzhang080, 2019-03-08:
It a cable problem.

Closed 2019-03-08.

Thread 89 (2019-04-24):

Couldn't find FONA

mjam9814, 2019-04-24:
Hey,

So I tried running the LTE Demo Sketch, it compiles properly but when i run the serial monitor, its just outputting random characters and at the end it say 'Couldn't find FONA' as shown in the screenshots below.

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

I'm using the botletics shield (SIM7000G)  with the arduino uno and the hologram simcard (which has been activated). All the LEDS(the two greens and the blinking blue) are on. I've followed each step so far in the instructables and I've downloaded all the libraries so I'm not sure where I've gone wrong.

botletics, 2019-04-27:
Please make sure you have the proper baud rate set in the serial monitor (9600) and don't change the LTE_Demo code in any way. It should work.

mjam9814, 2019-04-27:
The error shown in the screenshots happened when I used the original code and didn't change anything. So I guess I'll try to improve the solder joints and will let you know how it goes.

mjam9814, 2019-04-29:
So I tried to improve the solder joints as much as I could but it doesn't fix the problem. I have two of your shields (SIM7000G (v6) and SIM7000E (v5)) and the same thing happens to both. Could it be because of the Hologram SIM? I live in Sydney if that makes any difference.

botletics, 2019-04-29:
Do you see the green "PWR" LED turn on?

Please also check if your LiPo battery polarity is correct. The red wire should be on the left side of the connector when you plug it into the board.

mjam9814, 2019-04-29:
Yup, the LED turns on and the battery is in the correct polarity.

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

botletics, 2019-04-29:
Try unplugging the USB cable connected to the shield. It might be that you're trying to communicate with it via that USB at the same time the Arduino is trying to talk to it via UART.

mjam9814, 2019-04-29:
I’ve tried that, but still, its giving me the same error

botletics, 2019-04-29:
Hmm. Maybe something is wrong with your Arduino? I've never heard of this issue before.

mjam9814, 2019-04-29:
Yeah i was just trying that out to see if it worked and it did. Using Putty, it seems to responds to the commands

botletics, 2019-04-29:
Then the issue is likely with the solder joints on pins 10 and 11 or the Arduino itself, or a loose fit of the header pins into the Arduino headers.

mjam9814, 2019-04-29:
Ok then. I'll try to borrow another arduino from a friend and see it if that works. If not then its probably the connections. Do you happen to sell the shields with the headers already soldered on by any chance?

botletics, 2019-04-29:
Unfortunately no, they all come unsoldered since some people wire it up with other things and prefer to customize it.

mjam9814, 2019-04-30:
Am I still able to wire it externally to try and get it to work given that I've already soldered the female headers on?

mjam9814, 2019-05-02:
Used a different arduino and got it to work. Thanks!

Closed 2019-05-02.

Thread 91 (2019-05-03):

Connection issue

rajendran20, 2019-05-03:
Currently I am using uno with the botlectics shield with my IoT sim card (verified working). However there seems to be an issue when running LTE_demo code. I cant seem to register to the network. (status is 0). I am using USB to laptop with external power to uno.

When I plugged into the micro usb port of the shield to check AT commands using Putty, the shield comm ports becomes unstable (keeps going on and off). Not sure is it due to both uno and shield are connected to the laptop. Tried to use only the 9V external power to uno but still same.

However when I use a uno which is not able to be detected by the laptop (driver ic spoilt), my port for the shield is stable and I can invoke AT commands and able to confirm network can be registered (status 1).

Any advise on this weird issue?

botletics, 2019-05-06:
Please make sure you have a LiPo battery connected. That's really important for it to work!

rajendran20, 2019-05-06:
Hi Tim,

Will do that, thanks for getting back. One more thing, is there any connection diagram for connecting to ESP32 (nodemcu)? Or just need to connect UART interface?

Regards
Raj

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

botletics, 2019-05-06:
For ESP32 wiring please see the comments section of [the ESP demo code](https://github.com/botletics/SIM7000-LTE-Shield/tree/master/Code/examples/ESP32_LTE_Demo) and [the pinouts wiki page](https://github.com/botletics/SIM7000-LTE-Shield/wiki/Pinouts)

rajendran20, 2019-05-06:
Hi,

Thanks once again..great help

Regards
Raj

Get Outlook for iOS<https://aka.ms/o0ukef>
________________________________
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

rajendran20, 2019-05-07:
Hi Timothy,

Yes the LiPo battery was the issue. My shield was registered to the network after connecting to the LiPo batt. Afterwhich i downloaded IoT_example.ino for GPS tracking. I did encounter the following error where I encountered connection error.

Do you have any advise for me regarding this?

Found 'eeeeem!
---------------------
Latitude: -0.000000
Longitude: 0.000000
Speed: 0.00
Heading: 0.00
Altitude: 0.00
---------------------
 ---> AT+CIPSTATUS
 <--- OK
 <--- STATE: PDP DEACT
Connecting to MQTT...
 ---> AT+CIPSHUT
 <--- SHUT OK
 ---> AT+CIPMUX=0
 <--- OK
 ---> AT+CIPRXGET=1
 <--- OK
AT+CIPSTART="TCP","io.adafruit.com","1883"
 <--- OK
 <--- STATE: PDP DEACT
Connection failed
Retrying MQTT connection in 5 seconds...
 ---> AT+CIPSTATUS
 <--- OK
 <--- STATE: PDP DEACT
 ---> AT+CIPCLOSE
 <--- ERROR
 ---> AT+CIPSHUT
 <--- SHUT OK
 ---> AT+CIPMUX=0
 <--- OK
 ---> AT+CIPRXGET=1
 <--- OK
AT+CIPSTART="TCP","io.adafruit.com","1883"
 <--- OK
 <--- STATE: PDP DEACT
Connection failed
Retrying MQTT connection in 5 seconds...

Sent from Windows Mail

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

botletics, 2019-05-13:
Make sure your AdafruitIO credentials are correct on the sketch.

Closed 2019-06-10.

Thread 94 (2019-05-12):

Adafruit_SSD1306 Display Conflict

bliteknight, 2019-05-12:
I am currently using this board with an Arduino Uno and I cannot get it to work with a generic SSD1306 display.

Everytime I try to use the libraries together like in the code below, i get stuck in the **SSD1306 allocation failed** section of the code.

If I comment out **fonaSS.begin(9600);** then I get the display to work but then I can't use the shield.

Any thoughts?

```
#include <Wire.h>
#include <Adafruit_SSD1306.h>
#include <SoftwareSerial.h>
#include "Adafruit_FONA.h"

#define SCREEN_WIDTH 128 // OLED display width, in pixels
#define SCREEN_HEIGHT 64 // OLED display height, in pixels
#define FONA_RX 11 // Microcontroller TX
#define FONA_TX 10 // Microcontroller RX
#define FONA_PWRKEY 6
#define FONA_RST 7

// Declaration for an SSD1306 display connected to I2C (SDA, SCL pins)
Adafruit_SSD1306 display(SCREEN_WIDTH, SCREEN_HEIGHT, &Wire, -1);

uint8_t type;
char imei[16] = {0}; // MUST use a 16 character buffer for IMEI!
unsigned long time_now = 0;
SoftwareSerial fonaSS = SoftwareSerial(FONA_TX, FONA_RX);
SoftwareSerial *fonaSerial = &fonaSS;

float Voltage = 0.0;
const float multiplier = 0.1875F;
void setup() {
  Serial.begin(9600);
  if(!display.begin(SSD1306_SWITCHCAPVCC, 0x3C)) {
    Serial.println(F("SSD1306 allocation failed"));
    for(;;); // Don't proceed, loop forever
  } else {
    Serial.println(F("SSD1306 allocation success!!"));
  }

    // Clear the buffer
  display.clearDisplay();
  display.display();      // Show initial text
  delay(100);
  display.setTextSize(1); // Draw 2X-scale text
  display.setTextColor(WHITE);
  display.setCursor(0, 0);
  display.println("Hello World");
  display.display();

  // Show initial display buffer contents on the screen --
  // the library initializes this with an Adafruit splash screen.
  display.display();
  delay(2000);

  //LTE Setup
  Adafruit_FONA_LTE fona = Adafruit_FONA_LTE();
  pinMode(FONA_RST, OUTPUT);
  digitalWrite(FONA_RST, HIGH); // Default state
  pinMode(FONA_PWRKEY, OUTPUT);
  delay(100); // For SIM7000
  digitalWrite(FONA_PWRKEY, HIGH);
  //Connect to LTE

  Serial.println(F("FONA basic test"));
  Serial.println(F("Initializing....(May take several seconds)"));
  fonaSS.begin(115200); // Default SIM7000 shield baud rate
  Serial.println(F("Configuring to 9600 baud"));
  fonaSS.println("AT+IPR=9600"); // Set baud rate
  delay(100); // Short pause to let the command run
  fonaSS.begin(9600);
  if (! fona.begin(fonaSS)) {
    Serial.println(F("Couldn't find FONA"));
    while (1); // Don't proceed if it couldn't find the device
  }

  type = fona.type();
  Serial.println(F("FONA is OK"));
  Serial.print(F("Found "));
  switch (type) {
    case SIM800L:
      Serial.println(F("SIM800L")); break;
    case SIM800H:
      Serial.println(F("SIM800H")); break;
    case SIM808_V1:
      Serial.println(F("SIM808 (v1)")); break;
    case SIM808_V2:
      Serial.println(F("SIM808 (v2)")); break;
    case SIM5320A:
      Serial.println(F("SIM5320A (American)")); break;
    case SIM5320E:
      Serial.println(F("SIM5320E (European)")); break;
    case SIM7000A:
      Serial.println(F("SIM7000A (American)")); break;
    case SIM7000C:
      Serial.println(F("SIM7000C (Chinese)")); break;
    case SIM7000E:
      Serial.println(F("SIM7000E (European)")); break;
    case SIM7000G:
      Serial.println(F("SIM7000G (Global)")); break;
    case SIM7500A:
      Serial.println(F("SIM7500A (American)")); break;
    case SIM7500E:
      Serial.println(F("SIM7500E (European)")); break;
    default:
      Serial.println(F("???")); break;
  }

  // Print module IMEI number.
  uint8_t imeiLen = fona.getIMEI(imei);
  if (imeiLen > 0) {
    Serial.print("Module IMEI: "); Serial.println(imei);
  }

  // Set modem to full functionality
  fona.setFunctionality(1); // AT+CFUN=1
  fona.setNetworkSettings(F("TM")); // For Hologram SIM card
  fona.setPreferredMode(38); // Use LTE only, not 2G
  fona.setPreferredLTEMode(1); // Use LTE CAT-M only, not NB-IoT

  //Get Time
  char buffer[23];
  fona.getTime(buffer, 23);  // make sure replybuffer is at least 23 bytes!
  Serial.print(F("Time = ")); Serial.println(buffer);
}

void loop() {}
```

bliteknight, 2019-05-12:
FYI, root cause is a memory limitation of Arduino UNO

https://arduino.stackexchange.com/questions/62757/ssd1306-allocation-failed-when-include-sd-h

Using a different library [SSD1306Ascii](https://github.com/greiman/SSD1306Ascii/blob/master/examples/HelloWorldAvrI2c/HelloWorldAvrI2c.ino) helpd fix this issue.

Closed 2019-05-13.

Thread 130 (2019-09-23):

SIM7000C stuck in "Factory Test Mode"

logaeshKTBS, 2019-09-23:
My sim7000C module works fine till today morning. After creating some mess with at commands my module stucks in FTM(Factory Test Mode). Whenever i issued AT+CFUN? command via uart i got "+CFUN: 5" as a response. I can't issue "AT+CFUN=1" since it throws error.
I have issued "AT&F0" (Factory reset), but nothing helps. Please help me to get out from FTM.

botletics, 2019-09-23:
Worst case, try performing a firmware update and abort it after it resets the module.

logaeshKTBS, 2019-09-23:
Thank you for your reply. Still getting "+CFUN: 5" after restarting using "AT+CFUN=6".
I will try to update the frimware, but i had some queries,

1. We have designed a custom board with sim7000C and a 32-bit arm controller. Unfortunately we didn't take the USB pins(28, 27) out of the board. I only have access to UART pins(9, 10). Is it possible to upgrade the frimware using UART?

2. I didn't find any fimware file for sim7000C in your GitHub (SIM7000-LTE-Shield/SIM7000Documentation/Firmware/) page. where can i find one for SIM7000C?

botletics, 2019-09-23:
Sorry, I am not sure if you can update firmware via UART. You may be able to on UART3.
You may want to get the file from SIMCom. I do not have SIM7000C firmware.

hasikp1, 2019-11-22:
@botletics I got the same issue after a firmware update in SIM7000C. The update was successful but the module stuck at FTM

hasikp1, 2019-11-22:
Got it resolved, you have to restore xQCN file using QPST tool

eveready1010, 2020-01-15:
I have the same problem...  Upgraded the firmware (I think) and now it is stuck in factory test mode.  I tried all of the above and a few other suggestions at other sites, but no luck.  I have a battery pack installed.  I do not have a xQCN file from prior to the backup.
When I tried any of the other modes, the command looks like it succeeds, but after reboot it is still in mode 5.
Not sure what else to do.

eveready1010, 2020-01-18:
Anyone?  Not sure what else to do.  Google searches only turn up a few pages and none have worked so far.

botletics, 2020-01-18:
I think all you have to do is run the updater tool again and once it gets to a certain point just about it. You can also try the QPST tool.

eveready1010, 2020-02-22:
Ok, I have gotten the SIM7000 to go into CFUN=1, but now it will not connect:

Through Serial interface:

+CFUN: 1

+CPIN: READY

+CREG: 0,0

+CSQ: 31,99

+CPSI: NO SERVICE,Online

Through Arduino:

SIM7000/SIM7500 LTE Demo

Configuring to 9600 baud

Attempting to open comm with ATs

              ---> AT

              <---

              ---> AT

              <--- AT

              ---> ATE0

              <--- ATE0

              ---> ATE0

              <--- OK

              ---> ATI

              <--- SIM7000A R1351

OK

              ---> AT+CPMS="SM","SM","SM"

              <--- +CPMS: 0,10,0,10,0,10

FONA is OK

Found SIM7000A (American)

              ---> AT+GSN

              <--- 8652350xxxxxxxx

Module IMEI: 8652350xxxxxxxx

              ---> AT+CFUN=1

              <--- OK

              ---> AT+CGDCONT=1,"IP","hologram"

              <--- OK

FONA> G

              ---> AT+CIPSHUT

              <--- SHUT OK

              ---> AT+CGATT=1

              <---

Failed to turn on

FONA>

ERROR

I have also followed several of your “Getting Started” and other documents online several times and different ways and yet the result is still the same.

So, I am still wondering if although I got the firmware upgraded and working again maybe something still went wrong???

Also, in the Hologram.io website, it shows the device as active, but not connected and no IMEI number is shown after all of the extensive testing I performed.

At this point I am thinking that the module itself is corrupt…  Or, could it be something as simple as a bad antennae? Signal strength seems ok though.

Any suggestions?

Thank you.

Ed Thomas

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

botletics, 2020-02-24:
Check the "Connect to network" wiki page on GitHub. You may need to send the AT+CGDCONT command as well as AT+CMNP or AT+COPS to get connected.

eveready1010, 2020-02-24:
Well, that helped greatly!!!

It seems that somehow the module was stuck in manual mode (mode 1) for the command: AT+COPS

Once I restarted the module and then set it to mode 0, magically it started to work!

You don’t know how frustrating it was not to be able to get it to work after following all of those wiki articles several times before.

Thank you for your help!!!

(I guess persistence pays off!)

Ed

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

wicadmin, 2020-07-09:
> Ok, I have gotten the SIM7000 to go into CFUN=1, but now it will not connect

How did you get this to succeed? Was it at aborting during an upgrade?

eveready1010, 2020-07-09:
I am not 100% sure, but I believe it was because the battery did not have a full charge.  I accidentally left my Arduino on overnight which I had never done in the past, and the next day it finally worked.  So apparently leaving the Arduino on and everything connected overnight allowed the battery to get a full charge which the SIM7000 seems to require.

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

Tasosgi, 2021-01-18:
I got the same issue. I am using a 3Amp power supply but the CFUN is stuck to 5

WRedux, 2021-03-12:
>
>
> Got it resolved, you have to restore xQCN file using QPST tool.

Please: How exactly?

WRedux, 2021-03-12:
Solved it by myself.
Since I have the LilyGo and not the Botletics-Model, I guess, I have a different Flash-Software.
In mine, the xQCN-Option to parse the xQCN was set to "false" in the .ini of the Flash-Soft (SIM7000 QDL V1.43 Only for Update (backup&recover)), which is called cfg.ini.
Also the Option to ONLY do a xQCN-Flash (and not the complete Firmware) was set to "false".
(Since the Rest of the Firmware was OK, and shows up correctly)
I've set both to "true" and just updated my xQCN and finished up successful.

So my Problem of the not-showing-up IMEI and the Factory-Test (CFUN=5) are History now... :-)
Both appeared after a unsuccessful Firmware-Update (USB Connection got lost while update).

Closed 2019-09-23.

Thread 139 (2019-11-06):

Couldn't Find FONA

joelccrouch, 2019-11-06:
I keep getting "Couldn't find FONA". I have a Botletics SIM7000A that I purchased off of Amazon. The headers are soldered well, and I have board installed on a brand new UNO. I have a fully charged 1200mAH LiPo battery installed, and I am using Botletics modified FONA library (Botletics_SIMCom_Library_v1.0.1). The green PWR LED comes on and the blue NET LED is blinking.  I've tried pressing reset on Arduino, but that didn't help.  It doesn't matter what example I run. I get the following response:

SMS Response Test
Initializing....(May take several seconds)
Configuring to 9600 baud
Attempting to open comm with ATs
	---> AT
	<---
	---> AT
	<---
	---> AT
	<---
	---> AT
	<---
	---> AT
	<---
	---> AT
	<---
	---> AT
	<---
	---> AT
	<---
	---> AT
	<---
	---> AT
	<---
	---> AT
	<---
	---> AT
	<---
	---> AT
	<---
	---> AT
	<---
	---> AT
	<---
	---> AT
	<---
	---> AT
	<---
	---> AT
	<---
	---> AT
	<---
	---> AT
	<---
	---> AT
	<---
	---> AT
	<---
	---> AT
	<---
	---> AT
	<---
	---> AT
	<---
	---> AT
	<---
	---> AT
	<---
	---> AT
	<---
Timeout: No response to AT... last ditch attempt.
	---> AT
	<---
	---> AT
	<---
	---> AT
	<---
	---> ATE0
	<---
	---> ATE0
	<---
Couldn't find FONA

joelccrouch, 2019-11-06:
I tried a different cloned UNO from China, and it worked!

Closed 2019-11-06.

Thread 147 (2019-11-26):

Sim7000A enters boot loop on trying to disable data

spit4520, 2019-11-26:
Hello,

I am currently using your library for my production product. I love the documentation and all of the support around this project.

I have encountered a issue where modems will randomly enter a state where they cannot reconnect to the cell network and during the while loop for `fona.enableGPRS` I have unplugged the modem and let it sit for a while, I have also replaced the modem with other ones to remedy out hardware issues, but after a while they all end up being plagued with the issue.

The modem is used to connect over MQTT to our cloud and process commands for remote locks. I can strip out application logic and attach my set up and main loop code if that would be helpful

I hope to get some pointers soon on this, I will post debug logs as needed and src

Thanks,

Scott

botletics, 2019-12-02:
What SIM card are you using, and what do you get in response to the following command:

AT+CGREG?

Not being able to connect to the network would be the root of the problem, because if that's the case enabling data won't work.

spit4520, 2019-12-02:
I am using the Hologram simcard. Below is my logic for entering the loop.

The antenna I was using before spontaneously failed so I replaced it with a different one and the issue still persists.

Thanks for your reply

`
int8_r getSignal() {
  // read the RSSI
  uint8_t n = fona.getRSSI();
  int8_t r;

  Serial.print(F("RSSI = ")); Serial.print(n); Serial.print(": ");
  if (n == 0) r = -115;
  if (n == 1) r = -111;
  if (n == 31) r = -52;
  if ((n >= 2) && (n <= 30)) {
    r = map(n, 2, 30, -110, -54);
  }
  Serial.print(r); Serial.println(F(" dBm"));
return r;
}

bool hasService() {
  uint8_t n = fona.getNetworkStatus();
  Serial.print(F("Network status "));
  Serial.print(n);
  if (n == 0) Serial.println(F("Not registered"));
  if (n == 1) Serial.println(F("Registered (home)"));
  if (n == 2) Serial.println(F("Not registered (searching)"));
  if (n == 3) Serial.println(F("Denied"));
  if (n == 4) Serial.println(F("Unknown"));
  if (n == 5) Serial.println(F("Registered roaming"));
  if( n == 1 || n == 5) {
    return true;
  }
  return false;
}

 #if !defined(SIMCOM_3G) && !defined(SIMCOM_7500)
    // Disable data just to make sure it was actually off so that we can turn it on

    while(!hasService()){
      getSignal();
      delay(1000);
    }
    if (!fona.enableGPRS(false)) Serial.println(F("Failed to disable data!"));
    delay(1000);
    // Turn on data
    while (!fona.enableGPRS(true)) {
      Serial.println(F("Failed to enable data, retrying..."));
      delay(2000); // Retry every 2s
    }
    Serial.println(F("Enabled data!"));
  #endif
  mqtt.will(AIO_USERNAME "/feeds/message", "A,0,0");
  mqtt.subscribe(&topic_cmd);
  Serial.println(F("A,0,1"));
`

botletics, 2019-12-03:
Are you using a 3.7V LiPo battery to power the shield?

spit4520, 2019-12-03:
No, I am not using an official shield. I am using [this](https://www.amazon.com/gp/product/B07LCLPPRP/ref=ppx_yo_dt_b_asin_title_o00_s00?ie=UTF8&psc=1) for testing. I am powering the MCU and the modem off of my bench top PSU and it should be able to handle the current spikes. The modem was working before with your library with a few pin reassignments. Is the SIMCom modem especially suspect to current spikes?

botletics, 2019-12-03:
Sorry, I don't give support on other hardware.

spit4520, 2019-12-07:
I have bought the Sim7000G version of your shield now and this issue persists. I have been going back and forth with Hologram support for around 2 weeks and the issue still isn't resolved. The G version of your shield seems to connect to the T-Mobile 2G network, when I set the network preference to 38 (LTE only) the board is unable to connect to any cell tower. I am with in half a mile of a cell tower (I can see it outside my window) and I am surrounded by other sim com (sim7500) devices in my office so I know that the network shouldn't be the issue. I have connected a 3.7v battery to the shield and ensured that it has sufficient charge. I have also connected the supplied antenna from Pulse and left everything to sit for a hour or two and nothing reconnected.

OK
at+cops=?

+COPS: (1,"310 260","310 260","310260",0),(1,"310 410","310 410","310410",7),(1,"313 100","313 100","313100",7),(3,"311 480","311 480","311480",7),(3,"311 480","311 480","311480",9),,(0,1,2,3,4),(0,1,2)

I have went through all of the tutorials on hologram's site to clear the black lists [see here](https://support.hologram.io/hc/en-us/articles/360035697373-How-do-I-clear-the-FPLMN-list-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) and after a reboot the modem now cannot connect to the 2g network either :( I am very confused at this point and really would like some assistance.

`OK
at

OK
ati

SIM7000G R1529

OK
at+cgmi

SIMCOM_Ltd

OK
at+cgmm

SIMCOM_SIM7000G

OK
at+gmm

SIMCOM_SIM7000G

OK
at+cpin?

+CPIN: READY

OK
at+ccid

8944501810180176460f

OK
at+crsm=176,28539,0,0,12

+CRSM: 144,0,"FFFFFFFFFFFFFFFFFFFFFFFF"

OK
at+cfun?

+CFUN: 1

OK
at+csq

+CSQ: 19,99

OK
at+creg?

+CREG: 0,5

OK
at+cgreg?

+CGREG: 0,5

OK
at+cgdcont?

+CGDCONT: 1,"IP","hologram","0.0.0.0",0,0,0,0
+CGDCONT: 13,"IP","hologram","0.0.0.0",0,0,0,0

OK
at+cgact?

+CGACT: 1,0
+CGACT: 13,0

OK
at+cops?

+COPS: 0,0,"310 260 Hologram",0

OK
at+cops=?

+COPS: (1,"310 410","310 410","310410",7),(2,"310 260","310 260","310260",0),(1,"313 100","313 100","313100",7),(1,"311 480","311 480","311480",7),(1,"311 480","311 480","311480",9),,(0,1,2,3,4),(0,1,2)

OK`

botletics, 2019-12-10:
Please do a factory reset with the command "AT&F0" then load the LTE_Demo code and check network connection with "n".

spit4520, 2019-12-11:
FONA> i
	---> AT+CSQ
	<--- +CSQ: 99,99
RSSI = 99: -115 dBm
FONA> i
	---> AT+CSQ
	<--- +CSQ: 99,99
RSSI = 99: -115 dBm
FONA> n
	---> AT+CGREG?
	<--- +CGREG: 0,2
Network status 2: Not registered (searching)
FONA> n
	---> AT+CGREG?
	<--- +CGREG: 0,2
Network status 2: Not registered (searching)
FONA> i
	---> AT+CSQ
	<--- +CSQ: 99,99
RSSI = 99: -115 dBm
FONA>

I am also using the provided antenna. After my last post I disconnected it being very careful not to damage the UFL connector and placed it in a drawer, I have not ESD'ed onto it and been careful not to bend the edges.

I have a 2500 man battery connected and it is reporting to be at roughly 70% capacity.

I ran the AT&F0 command with ATE enabled and received no error command nor did I receive an OK acknowledgment.

Any Ideas?

Thank you

botletics, 2019-12-16:
Have you read [this wiki page](https://github.com/botletics/SIM7000-LTE-Shield/wiki/Connecting-to-Network)?

spit4520, 2019-12-18:
CSQ: 99,99

OK

+CSQ: 99,99

OK

OK
ate

OK
ate

OK
ati

SIM7000G R1529

OK
ate

OK
ati

SIM7000G R1529

OK
at+ccid

8944501810180176460f

OK
at+csq

+CSQ: 99,99

OK

NORMAL POWER DOWN
 at

OK
ate

OK
ati

SIM7000G R1529

OK
at+ccid

8944501810180176460f

OK
AT+CGDCONT

OK
AT+CGDCONT?

+CGDCONT: 1,"IP","hologram","0.0.0.0",0,0,0,0
+CGDCONT: 13,"IP","hologram","0.0.0.0",0,0,0,0

OK
at+csq

+CSQ: 99,99

OK
at+csq

+CSQ: 99,99

OK
at+cops?

+COPS: 0

OK
at+cops=?

+COPS: (1,"313 100","313 100","313100",7),(1,"311 480","311 480","311480",7),(1,"310 410","310 410","310410",7),(1,"310 260","310 260","310260",0),(1,"311 480","311 480","311480",9),(1,"310 410","310 410","310410",9),,(0,1,2,3,4),(0,1,2)

OK
at+csq

+CSQ: 99,99

OK
AT+CGMR

Revision:1529B01SIM7000G

OK
at+cnmp?

+CNMP: 2

OK
at+cnmp=?

+CNMP: ((2-Automatic),(13-GSM Only),(38-LTE Only),(51-GSM And LTE Only))

OK
at+cnmp=38

OK
at+cnmp?

+CNMP: 38

OK
at+cmnb=?

+CMNB: ((1-Cat-M),(2-NB-IoT),(3-Cat-M And NB-IoT))

OK
at+cmnb?

+CMNB: 3

OK
at+cmnb=1

OK
at+cbandcfg?

+CBANDCFG: "CAT-M",1,2,3,4,5,8,12,13,18,19,20,26,28,39

+CBANDCFG: "NB-IOT",1,2,3,5,8,12,13,17,18,19,20,26,28

OK
at+cbandcfg=?

+CBANDCFG: (CAT-M,NB-IOT),(1,2,3,4,5,8,12,13,17,18,19,20,26,28,39)

OK
at+cops=?

+COPS: (3,"311 480","311 480","311480",7),(1,"310 260","310 260","310260",0),(3,"313 100","313 100","313100",7),(1,"310 410","310 410","310410",7),,(0,1,2,3,4),(0,1,2)

OK
at+cops=1,3,"313100"

ERROR
at+cops?

+COPS: 0

OK
at+cops=1,3,"311480",7

ERROR

I ran all of the diagnostics from the debug page and after letting it sit for about an hour it eventually reconnected.

My questions stems from if there is any way to speed this process up, or streamline the process? I have really enjoyed all of the support you have given me and enjoy your board.

Best,

Scott

botletics, 2019-12-23:
Please make sure you have a 3.7V LiPo battery plugged in with the right polarity. The red wire should be on the left side of the connector when you plug it in.

Closed 2019-12-03.

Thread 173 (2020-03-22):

RSSI of -115 dBm

Naoki95957, 2020-03-22:
Hello! I've done everything about as cookie-cutter as the wiki has explained it. I'm a bit confused based on what's in front of me however...
Hardware:
Botletics SIM7000G
2Ah Lipo
Hologram.io sim
gps/lte antenna hooked up
shield attached to arduino
usb from my machine to arduino

The result is a blinking net led, which would appear communication is operating correctly, right? its blinking about twice per second.

When I launch the LTE demo and 7XXX LTE demo, and query a few things like the battery voltage or SIM CCID, it would appear everything is correct. It's just that due to signal being  non-existent I can't do much/anything

botletics, 2020-03-23:
The network (blue) LED blinking quickly indicates it's not connected, unless it's blinking very rapidly, which means it's connected and data is activated (but I don't think that's your case).

Please see [this wiki page](https://github.com/botletics/SIM7000-LTE-Shield/wiki/Connecting-to-Network) if you're having problems connecting to a network.

pmethods, 2020-03-23:
FYI I validated the botletics branch of the FONA library against a SIM5320A.  It works exactly as described and the sections (2) and (3) are a perfect starting example for doing generic HTTP interfacing (for roll your own IoT)

I extended the library out to (4), (5), (6) for pulling a timestamp down from AWS, Generatring Version 4 signing certificates, and performing an arbitrary file upload to Amazon S3.

botletics wrote a very thoughtful interface that is compatible with a wide range of hardware sets, including stuff offered by other vendors.  If you are having troubles it is ok. . .   this is complicated stuff with a lot of details.  Rest assured that your hardware and software will work - you just have to keep focused on the details and work hard to understand all of it.

Good Vendor to do business with!
Gets my thumbs up.

-methods

Naoki95957, 2020-03-23:
I appreciate the swift replies! I'll dig thru the wiki some and try to figure it out.. I haven't had a lot of time to play with the unit and the initial one I messed with (7000A) worked out of the box. I had a few things land on me recently but I'm very eager to work with these assets and this product! I'll report back and consider this closed unless I come across another roadblock.

Naoki95957, 2020-03-30:
Yay, so this link helped me. I couldn't get the 'serial tube' from the Arduino sketch to work, but after getting a micro usb and installing the windows drivers, I was able to do some AT commands which resolved the issue. Particularly after setting the '+CNMP' and '+CNMB' to automatic/both options. Thanks!

> Please see [this wiki page](https://github.com/botletics/SIM7000-LTE-Shield/wiki/Connecting-to-Network) if you're having problems connecting to a network.

Closed 2020-03-23.

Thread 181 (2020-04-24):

USB not waking up

rgillan, 2020-04-24:
Hello, I have a recently purchased v6 7000G module and trying to get connectivity up via the USB.  We are running it on an anti static bench, with a solid 5V supply (to +5/GND) and correctly polarised 5000mAh LiPo connected.  The unit wakes up as far as the green power light goes, with the blue netlight flashing on ~1s cadence (indicating that it's not locked LTE).  We have tried with and without SIM but no difference.  We have tried with a Windows machine, a RPi3 and a NanoPi Neo2 (our final target).  If we plug a simple serial/USB converter into either linux machine lsusb shows the device, and there's a ttyUSB0 port in /dev.  When we plug in the USB from the shield we get nothing.  We have verified that the LTE PWR pin also starts/stops the shield (again, the LEDs light).  We must be missing something very basic and any help gladly appreciated.

botletics, 2020-04-24:
Hi there, please make sure you've read [this page] (https://github.com/botletics/SIM7000-LTE-Shield/wiki/USB-Drivers) to install the USB drivers, then see [this page] (https://github.com/botletics/SIM7000-LTE-Shield/wiki/Connecting-to-Network). For the SIM7000G you will likely need to use the commands to narrow down the band selection to get it to connect.

rgillan, 2020-04-24:
Thanks for the prompt response.  Yes we have already gone through the USB driver process on Ubuntu/Armbian (which already has the Qualcomm driver module), Raspberry Pi and Windows 7.  When the device is plugged into the USB port it does not even register with lsusb or the Device Manager.  We have left the charger on overnight and indeed we now have the power led, the ready/charged led and the flashing network led (but not connected, that's not our issue, it's the basic USB waking up).  The only connections we have to the unit are a 3A/5V and ground connection from a power supply; the LiPo and the USB cable.  We have validated that there is a 5V signal on the V_BUS signal coming in so the 7000 should be detecting that the USB is active, it's just appearing not to.  As there's no circuitry between the micro USB and the 7000 the only thing we can think of is that the 7000 is faulty unless we're missing something totally obvious.  Suggestions gladly accepted.

botletics, 2020-04-24:
Please check to make sure the LiPo battery has proper polarity. The red wire should be on the left side of the JST connector when you plug it into the board. Some manufacturers flip the polarity.

rgillan, 2020-04-24:
Yes, we've done that, and checked the voltages/polarity with a DMM (we did change the polarity on the LiPo before we first connected it).  The resultant voltage on VIN is measuring within the operating range of the 7000.  We're a bit stumped.

botletics, 2020-04-24:
Hmmm yea if the voltage is right and the green "PWR" LED is on (with blue NET light as well) then it should show up in device manager as long as your USB cable isn't a power-only cable.

rgillan, 2020-04-24:
Hmm, we've changed USB cables a number of times but will pull out a new one we know is not just power and see (now that would be embarrassing ;) ).  Really appreciate your responsiveness, thank you

rgillan, 2020-04-24:
Well Timothy there's times in your life we're you miss really simple things, and this was one of them.  Turns out the 6 or 7 cables we tested are power only.  Being an Apple shop this whole microUSB thing is only to power devices.  We have pulled a new cable out of a bag that we know is a data cable and voila.  On the Armbian target (which already has the Qualcomm driver) all the ttyUSBx ports immediately pop up (sigh).  Thanks for your help and we'll let you know if there are any issues (but doubt it now)

botletics, 2020-04-24:
Haha, happens to the best of us... glad you got it working!

Closed 2020-04-24.

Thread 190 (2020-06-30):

GPS location not being found

Alfredfoby, 2020-06-30:
When I use the code given for the IoT and comment out most of the temperature sensor code since it wasn't working for me I get stuck in the while loop that prints "Failed to get gps location" I'm talking about this loop below
while (!fona.getGPS(&latitude, &longitude, &speed_kph, &heading, &altitude)) {
Serial.println(F("Failed to get GPS location, retrying..."));
delay(2000); // Retry every 2s
}

I decided that maybe it was an error and removed the not sign "!" and then it goes through the loop

to next part of the code, the problem now is that I get the wrong latitude and longitude and I also don't get any data for the heading. The longitude and latitude show that I am in Kenya when in reality I am in the United States.

I hope someone can help me.

botletics, 2020-07-01:
Hi, please post a serial monitor log so we can debug, thanks.

Alfredfoby, 2020-07-01:
I have attached the log below, I dont seem to see anything wrong but its just not working.

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

osy93, 2020-07-02:
Hi Tim, first of all thanks a lot for all the hard work put in this project - I just got the shield and its awesome !

I have the same issue above (my location is in Dubai, UAE), would really appreciate your input !

Regards,
Osama

botletics, 2020-07-02:
Sometimes it takes a couple minutes to get a fix on GPS. How long did you wait?

Alfredfoby, 2020-07-02:
I waited for an hour at some point and still couldn't find a location.

Alfredfoby, 2020-07-02:
I was hoping it had to do with some of the pins that weren't enabled and were commented out in the sketch

botletics, 2020-07-02:
No, as long as GPS was enabled you should get a fix on GPS location eventually. However, inside some buildings there may not be a good signal. If power consumption is not a concern at all you could try soldering the solder jumper labeled "ACTV" on the board (for v6 boards only) and attach an active GPS antenna.

Alfredfoby, 2020-07-02:
It is finally working, All i had to do was taking the arduino for a ride haha, i drove with the modem and arduino for some time and it finally started working. I was just in an area where the gps wasn't working for some reason.

Thank you very much for everything.

ishdemon, 2021-03-30:
As long as you are getting reply from AT+CGNSINF, its working fine. Mine just doesn't reply at all, stuck in a loop :

```
AT+CGNSINF
AT+CGNSINF
AT+CGNSINF
AT+CGNSINF
AT+CGNSINF
AT+CGNSINF
AT+CGNSINF
```
was searching through issues if someone also had this problem. Sometimes after reset it works fine for a while.

Closed 2020-07-02.

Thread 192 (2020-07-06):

can't turn on cellular data or gps

andrewhong5297, 2020-07-06:
Using botletics 7000A and hologram sim card, after running LTE_demo the G and O commands don't work for me. I can read network time and signal strength though. Any idea what might be going wrong?

Both green lights are working (is there a way to make these lights dimmer?), and the net light is blinking blue.

botletics, 2020-07-06:
Sounds like you don't have a LiPo battery attached and it's probably powering off when you try to enable those functions.

andrewhong5297, 2020-07-06:
forgot to mention I have a lipo 3.7v plugged in - is there some indicator to tell if it is on or not?

botletics, 2020-07-06:
Please check the polarity of the LiPo battery wires. The red wire should be on the left side of the connector when you plug it into the board.

The green "PWR" LED indicates whether or not the SIM7000 is powered on.

andrewhong5297, 2020-07-06:
Here's my setup, I cant plug the lipo in any other way.

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

botletics, 2020-07-06:
Yea that's the problem. Your battery polarity is backwards. Please order a LiPo battery with a minimum of 500mAH capacity, preferably 1000mAH+, from either Adafruit or Sparkfun (can be found on Amazon as well). There are many knock-offs and some have reversed polarity. Your battery also looks pretty small.

andrewhong5297, 2020-07-08:
Can you find an amazon link with correct batteries? I've ordered three times already but its always either the head is slightly off or polarity is wrong. Would greatly appreciate it!

andrewhong5297, 2020-07-09:
for example, they all seem to be like this https://www.amazon.com/YDL-1700mAh-battery-Rechargeable-Connector/dp/B07BTRTR9R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

botletics, 2020-07-09:
I know [this one will work](https://www.amazon.com/dp/B00J2QET64?ref=ppx_pop_mob_ap_share)

andrewhong5297, 2020-07-10:
Thank you!

Closed 2020-07-06.

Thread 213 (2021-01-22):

Adafruit stops receiving data after sometime.

Alfredfoby, 2021-01-22:
So I am having an issue where I am publishing values to adafruit lets say every 30 seconds. The issue I'm facing is that it would send data to adafruit io for maybe a few hours, sometimes a few days then stop sending data completely and randomly send one piece of data to adafruit io and stop again for days and days.

I put a bunch of print statements and realized it is stuck in the while loop doing the mqtt.connect() function and I am not sure what to do to fix it. I initially thought it was an issue with the modem and hologram sim card data plan but that doesn't seem to be the case as I talked to hologram already.

This is the loop I am talking about.

`while ((ret = mqtt.connect()) != 0) { // connect will return 0 for connected
      Serial.println(mqtt.connectErrorString(ret));
      Serial.println("Retrying MQTT connection in 5 seconds...");
      mqtt.disconnect();
      delay(5000);  // wait 5 seconds
    }
    Serial.println("MQTT Connected!");`

It would be of great help as I am blind to monitoring my devices.

botletics, 2021-01-22:
Worst case, you could put a counter variable in the while loop that is incremented every time the reconnection fails, then when counter reaches XX number of attempts, you restart the SIM7000 module using AT+CFUN=6 to do a software reset.

Alfredfoby, 2021-01-22:
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

I have done that but theres still no luck with publishing to adafruit. I have ran out of ideas.

botletics, 2021-01-22:
Is it losing network connection altogether?

Alfredfoby, 2021-01-22:
> Is it losing network connection altogether?

Yes I believe so,  in mqtt.connect() function it never seems to connect. Could it have something to do with mqtt.keepalive() window?

botletics, 2021-01-22:
- Do you have a LiPo battery connected? (Make sure red wire is on the left side when you plug it into the connector)
- So even after a soft restart, the module doesn't connect to the network? What do you typically do to get it connected again? - You should probably put a network registration (with getNetworkStatus) before even attempting to connect via MQTT. What signal strength do you typically get when it's connected?
- What if you did something like this instead of soft-restarting the SIM7000:

```
uint8_t counter = 0;

while ((ret = mqtt.connect()) != 0) {
  Serial.println(mqtt.connectErrorString(ret));
  Serial.println("Retrying MQTT connection in 5 seconds...");
  counter++; // Increment counter
  mqtt.disconnect();
  if (counter == 10) {
    // fona.setFunctionality(6); // AT+CFUN=6 to soft restart the SIM7000

    fona.setFunctionality(1); // AT+CFUN=1
    fona.setNetworkSettings(F("hologram"));
    fona.enableGPRS(true); // Turn on data
    delay(2000); // Pause before retrying to connect
  }
  else {
    delay(5000);
  }
}

Serial.println("MQTT Connected!");
```

Alfredfoby, 2021-01-22:
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

So i am doing all that you have in your code already with the exception of fona.enableGPRS() because I am not using the gps side of things.

- I have the LiPo battery connected already
- I don't do anything to connect it again, it typically connects on its own then works for a while and stops again. or if i leave the system off for days then it works for a bit and stops.
- I am not really sure the signal strength but I used the signal quality at command,  AT+CSQ and i got 20,99 which is excellent i believe.
-

botletics, 2021-01-22:
enableGPRS is for data connection, not GPS.

Alfredfoby, 2021-01-22:
> enableGPRS is for data connection, not GPS. Also, you could try sending "AT&F0" one time to factory reset the module and run your usual code again.

I will try that soon and give you an update, I am inclined to believe it has something to do with the hologram network not connecting to the internet. But I may be wrong as well.

Alfredfoby, 2021-01-26:
> enableGPRS is for data connection, not GPS. Also, you could try sending "AT&F0" one time to factory reset the module and run your usual code again.

Okay i think I need to send enableGPRS before it actually sends the data.
It is working currently and I will continue to update you, Thanks for the help.

Alfredfoby, 2021-02-01:
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

So it is currently not working anymore, it is almost as if a buffer or something gets full on the modem and it needs some sort of reset because it completely stopped on its own and I've been trying to get it to send data even after resetting the modem for the past 3 days

Alfredfoby, 2021-02-02:
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

I figured that every time it stops communicating I would do a hard reset of the modem. And that seems to be working when i send AT&F0 and reset the modem.

Is there a way to do this with arduino code maybe using the reset pin??

botletics, 2021-02-02:
Yes, you can use the `FONA_RST` pin in the Arduino code to reset it by pulsing it LOW for at least 252ms, according to Table 10 of the SIM7000 hardware design doc. You can also invoke the AT+CFUN=6 command by using the Arduino code `fona.setFunctionality(6)`

Closed 2021-01-31.

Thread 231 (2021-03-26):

IoT Example Issues.

mduiop, 2021-03-26:
First I tested with the LTE_DEMO to make sure I could connect to data, send a GET header, and receive GPS Coords.  I then ran the IoT_Example using Hologram and sending a GET header.  I think the only thing I changed was the frequency to send the GET header to 5 minutes.

First thing I notice is that the moduleSetup function keeps on line 201 is getting called in a loop over and over.  I say this because (I added debugging output and) the serial monitor keeps repeating "FONA is OK. Found ???"   I found that "type = fona.type();" type had the value of "7" so I changed the switch/case

case SIM7000:
      Serial.println(F("SIM7000")); break;

to

case 7:
      Serial.println(F("SIM7000")); break;

(which happens to be the 7th case) and now it prints SIM7000

That stopped it from printing "Found ???" but still this function seems to get called over and over many times. Eventually the next line (202) is reached.

Then it will usually not find GPS or GPRS . . .
the one time it did actually get to the line of code that sent the header I did receive a HTTP 601 error.

I am wondering if I am doing anything wrong.  Again, LTE_Demo allowed me to sent the GET header, etc.

Thanks

mduiop, 2021-03-26:
To update I moved to a different physical location, and it is connecting, attempting to send the HTTP Get header to my web server, but I am receiving a 601 error.  If I copy and paste the URL (with the query string) from the terminal (that the script is attempting to send) into a browser's command line then the browser based application will process the data in the query string . . . so there does not seem to be any issues with the web app that is causing the 601 error.  Thanks

mduiop, 2021-03-27:
At this point the following just loops over and over again.  I am new to Arduino and C/C++ but thought that since this function is not called in the main loop it shouldn't repeat over and over.  It's as if it's being reset somewhere.  I am using the Lipo battery, and the green "done" light is illuminated on the board as well as another green light and flashing blue light (LEDs).  Again, I use LTE_Demo first to check I can make a network connection and then run the IoT_Demo and get this:

** SIMCom Module IoT Example ***
Configuring to 9600 baud
Attempting to open comm with ATs
---> AT
<--- OK
---> ATE0
<--- OK
---> ATE0
<--- OK
---> AT+GMR
<--- Revision:1351B03SIM7000A

OK

---> AT+CPMS="SM","SM","SM"
<--- +CPMS: 1,10,1,10,1,10
FONA is OK
Found SIM7000A (American)
---> AT+GSN
<--- 86⸮*** SIMCom Module IoT Example ***
Configuring to 9600 baud
Attempting to open comm with ATs
---> AT
<--- OK
---> ATE0
<--- OK
---> ATE0
<--- OK
---> AT+GMR
<--- Revision:1351B03SIM7000A

OK

---> AT+CPMS="SM","SM","SM"
<--- +CPMS: 1,10,1,10,1,10
FONA is OK
Found SIM7000A (American)
---> AT+GSN
<--- 8⸮*** SIMCom Module IoT Example ***
Configuring to 9600 baud
Attempting to open comm with ATs
---> AT
<--- OK
---> ATE0
<--- OK
---> ATE0
<--- OK
---> AT+GMR
<--- Revision:1351B03SIM7000A

OK

botletics, 2021-03-27:
Looks like you're running out of memory. Try upgrading to an Arduino Mega instead of an Uno (which I'm assuming you're using?)

mduiop, 2021-03-27:
Hi am using the Mega actually. Thanks

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

botletics, 2021-03-27:
I just tried the unaltered IoT_Example sketch on my Arduino Uno and it worked.

mduiop, 2021-03-27:
UPDATE: I noticed that the IoT_Example sketch was updated on Github a few minutes ago. I used that version, and now it did work.  Posts GPS coords to my PHP script on a web server then emails me the data. I am having a bit of trouble locking onto a GPS signal so it only worked intermittently then obviously wont send data unless it gets coordinates.  That could be my geographic location.  I'll try it on a drive later.  I will probably go for a powered GPS antenna unless you have other suggestions for improving ability to connect to GPS signal, and data network . . . I notice that I either connect to T-Mibile or AT&T via Hologram so maybe uncommenting some of those variables for forcing certain networks would help?  Thanks!

botletics, 2021-03-27:
GPS is completely independent of the network, so your best bet to improving the signal would be an active GPS antenna.

mduiop, 2021-03-27:
Yes, my comment was a little unclear, sorry.  I understand that network issues and GPS issues are two separate things.  I am having a little trouble with both.  I will take your advice for the GPS and use an active antenna.  For the benefit of anyone looking here for help, I will solder a jumper between the two points on the Botletics board required when using a powered antenna.  For signal strength I will research antennas for that purpose, but was wondering if forcing a certain network protocol would improve things by un-commenting some of the variables . . . probably not . . . just a thought.  Thanks again.

botletics, 2021-03-28:
No, I don't think locking any cellular mode or band will help you. If it's a signal issue, your best bet is to get a better antenna.

Closed 2021-04-06.

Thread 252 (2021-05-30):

Done LED doesn't illuminate when supplied 4.2V on VBAT

davegravy, 2021-05-30:
Everything else on the module is working as expected for me so far (I'm connected to the Rogers LTE-M network)

The "Done" LED doesn't illuminate. I'm powering it with a bench supply capable of 3A output and I've increased the VBAT supply as far as 4.27V.

I have no Arduino connected, only my PC via USB.

botletics, 2021-06-01:
If you don't have an actual LiPo battery connected to it, don't worry about the DONE LED.

davegravy, 2021-06-01:
I'm only worried because I will ultimately have a LiPo connected.

However I was not supplying anything to the 5V pin, expecting my usb cable to the pc would provide this. When I supply to the 5V pin as well as VBAT the done LED now illuminates.

Closed 2021-06-01.

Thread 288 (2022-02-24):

MQTT Example, keep resetting

dnwk, 2022-02-24:
I loaded MQTT example to my Arduino UNO and SIM7000C, it keeps resetting. I do have battery attached and LTE_demo runs ok.

** SIM7000 MQTT Example ***
20:39:54.689 -> Configuring to 9600 baud
20:39:54.792 -> Attempting to open comm with ATs
20:39:54.861 -> 	---> AT
20:39:54.861 -> 	<--- OK
20:39:54.895 -> 	---> ATE0
20:39:54.928 -> 	<--- OK
20:39:55.065 -> 	---> ATE0
20:39:55.065 -> 	<--- OK
20:39:55.232 -> 	---> AT+GMR
20:39:55.737 -> 	<--- Revision:1529B01SIM7000G
20:39:55.770 ->
20:39:55.770 -> OK
20:39:55.770 ->
20:39:55.770 -> 	---> AT+CPMS="SM","SM","SM"
20:39:55.840 -> 	<--- +CPMS: 0,30,0,30,0,30
20:39:55.874 -> FONA is OK
20:39:55.874 -> Found SIM7000
20:39:55.874 -> 	---> AT+GSN
20:39:55.907 -> 	<--- 86

It just keeps repeating above.

dnwk, 2022-02-24:
Now it is doing this

20:57:08.013 -> 	---> AT+GSN
20:57:08.013 -> 	<--- 869[IMEI number]
20:57:08.047 -> Module IMEI: 869[IMEI number]
20:57:08.081 -> ⸮gO #⸮⸮߮Yᱷ⸮⸮⸮*** SIM7000 MQTT Example ***

I notice the gibberish output after IMEI. Baud rate issue?

dnwk, 2022-02-24:
em... I really didn't do anything now my Arduino can't communicate with the SIM7000. No response from AT command. USB direct connection to my computer still works. Did some components fail on the board?

botletics, 2022-02-24:
Does the battery have the correct polarity? Red wire should be on the left side of the connector when you plug it into the board.

dnwk, 2022-02-24:
Yes, I have confirmed battery connection is correct

botletics, 2022-02-24:
Please check the physical connection on pins 10-11 on the shield. If the green "PWR" LED on the board is staying on but you're not able to communicate with it, this may indicate an issue with the hardware connection being flaky.

Closed 2022-03-03.

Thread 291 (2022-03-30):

Flashing failed.

richcj10, 2022-03-30:
I have tried the SIM7000 program and QPST tool. Both fail for the modem (Botletics board) not responding to Sahara boot loader. I  see the the board go down to be "reset" into boot loader mode. But the device stays down and it has to be reset or power cycled. I am using a 1.2Ah LiPo Battery. Testing with the modem has gone well otherwise. I have been able to make connections to the outside world. I just need the update to do HTTPS. (Pushover)  Any thoughts?

richcj10, 2022-03-30:
Soldering Pin 6 to 1.8V fixed my update issue. This should be broken out in the future.

Closed 2022-04-11.

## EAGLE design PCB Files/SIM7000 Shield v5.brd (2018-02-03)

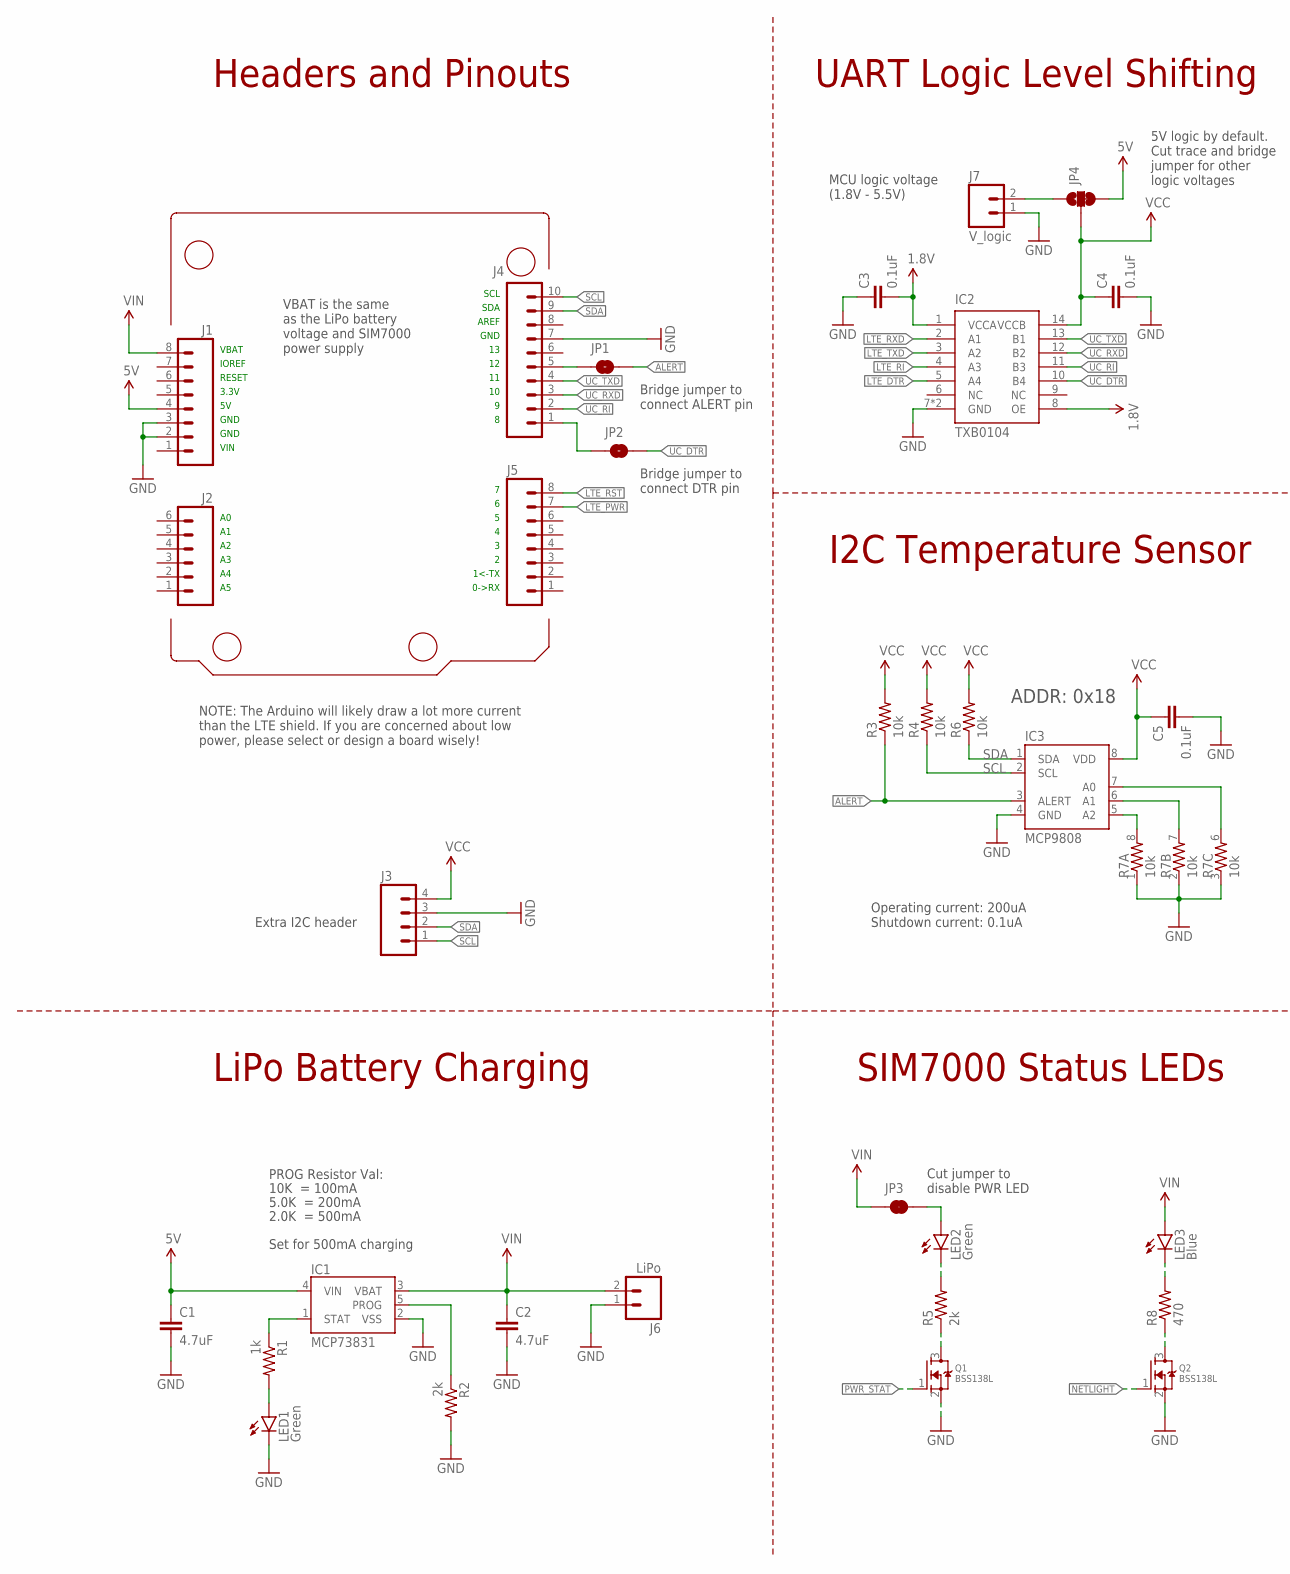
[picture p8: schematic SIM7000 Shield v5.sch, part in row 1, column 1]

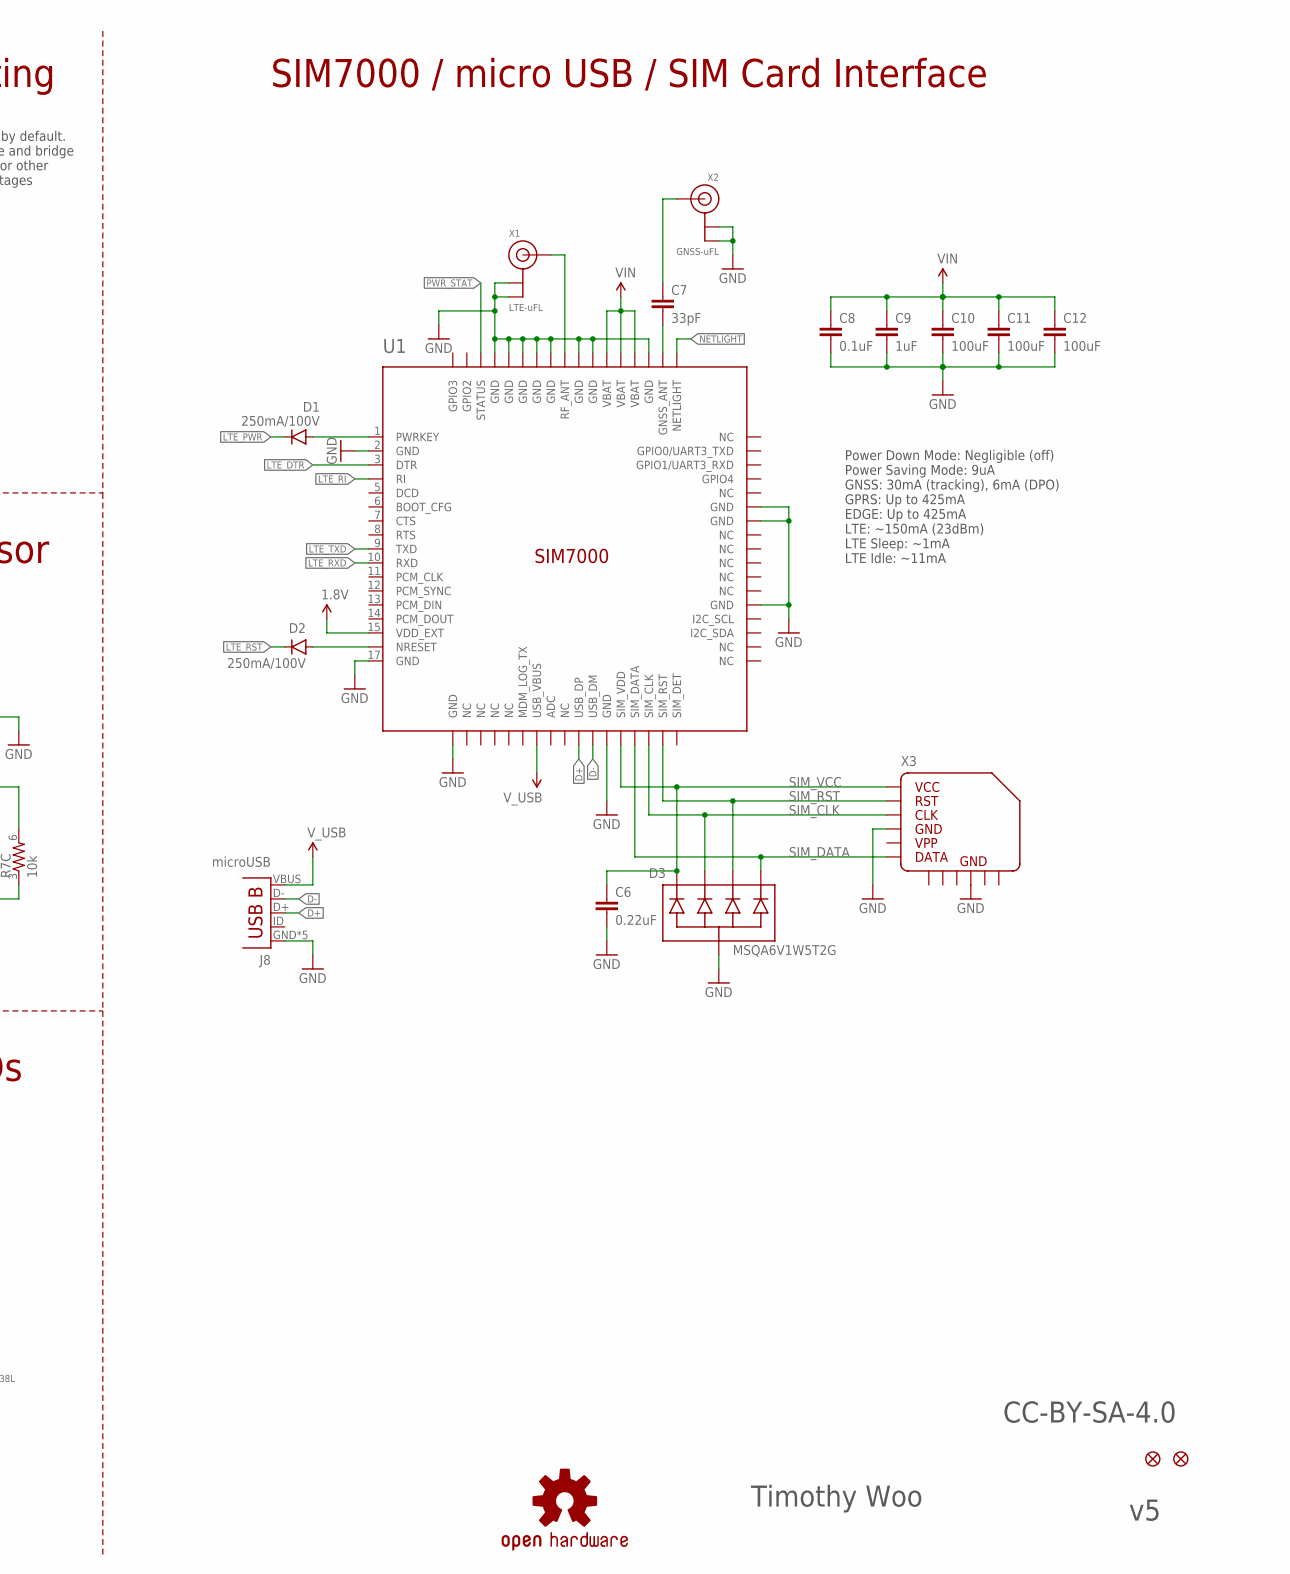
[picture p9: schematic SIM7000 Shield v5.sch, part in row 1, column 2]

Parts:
C1, C2: 4.7uF; 0603-CAP-MARKED
C3, C4, C5, C8: 0.1uF; 0603-CAP-MARKED
C6: 0.22uF; 0603-CAP-MARKED
C7: 33pF; 0603-CAP-MARKED
C9: 1uF; 0603-CAP-MARKED
C10, C11, C12: 100uF; 1210
D1, D2: 250mA/100V; SOD-323
D3: MSQA6V1W5T2G; SOT-353
FID1, FID2: FIDUCIAL; FIDUCIAL_1MM
IC1: MCP73831; SOT23-5
IC2: TXB0104; VQFN-14
IC3: MCP9808; 8-TSSOP
J1, J5: M08SILK_PTH; 1X08
J2: M06SILK_PTH; 1X06
J3: M04PTH-ROUND; 1X04_ROUND
J4: M10SILK_PTH; 1X10
J6: LiPo; JST-2-SMD
J7: V_logic; 1X02
J8: microUSB; USB-B-MICRO-SMD
JP1, JP2: JUMPER-SMT_2_NO_SILK; SMT-JUMPER_2_NO_SILK
JP3: JUMPER-SMT_2_NC_TRACE_SILK; SMT-JUMPER_2_NC_TRACE_SILK
JP4: JUMPER-SMT_3_1-NC_TRACE_SILK; SMT-JUMPER_3_1-NC_TRACE_SILK
LED1, LED2: Green; LED-0603-MARKED
LED3: Blue; LED-0603-MARKED
LOGO1: OSHW-LOGOL; OSHW-LOGO-L
Q1, Q2: BSS138L; SOT23-3
R1: 1k; 0603-RES-MARKED
R2, R5: 2k; 0603-RES-MARKED
R3, R4, R6: 10k; 0603-RES-MARKED
R7: 10k; RES_ARRAY_4X0603
R8: 470; 0603-RES-MARKED
U1: SIM7000
X1: LTE-uFL; U.FL
X2: GNSS-uFL; U.FL
X3: MICROSIM_SOCKET_PUSH-PULL

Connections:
1.8V: C3.2, IC2.1 (VCCA), IC2.8 (OE), U1.15 (VDD_EXT)
5V: C1.1, IC1.4 (VIN), J1.4, JP4.3
ADDR0: IC3.7 (A0), R7.6 (2)
ADDR1: IC3.6 (A1), R7.7 (2)
ADDR2: IC3.5 (A2), R7.8 (2)
ALERT: IC3.3 (ALERT), JP1.2, R3.1
D+: J8.D+, U1.27 (USB_DP)
D-: J8.D-, U1.28 (USB_DM)
GND: C1.2, C2.2, C3.1, C4.2, C5.2, C6.2, C8.2, C9.2, C10.2, C11.2, C12.2, D3.2 (COM), IC1.2 (VSS), IC2.7 (GND), IC2.PAD (GND), IC3.4 (GND), J1.2, J1.3, J3.3, J4.7, J6.1 (2), J7.1, J8.GND, J8.SHIELD1 (GND), J8.SHIELD2 (GND), J8.SHIELD3 (GND), J8.SHIELD4 (GND), LED1.C, Q1.2 (S), Q2.2 (S), R2.2, R7.1, R7.2 (1), R7.3 (1), U1.2 (GND), U1.17 (GND), U1.18 (GND), U1.29 (GND), U1.39 (GND), U1.45 (GND), U1.46 (GND), U1.54 (GND), U1.58 (GND), U1.59 (GND), U1.61 (GND), U1.62 (GND), U1.63 (GND), U1.64 (GND), U1.65 (GND), X1.1 (GND), X1.2 (GND), X2.1 (GND), X2.2 (GND), X3.C5, X3.GND@1 (GND), X3.GND@2 (GND), X3.GND@3 (GND), X3.GND@4 (GND), X3.GND@5 (GND), X3.GND@6 (GND)
LTE_DTR: IC2.5 (A4), U1.3 (DTR)
LTE_PWR: D1.C, J5.7
LTE_RI: IC2.4 (A3), U1.4 (RI)
LTE_RST: D2.C, J5.8
LTE_RXD: IC2.2 (A1), U1.10 (RXD)
LTE_TXD: IC2.3 (A2), U1.9 (TXD)
unnamed: C7.2, U1.53 (GNSS_ANT)
unnamed: D1.A, U1.1 (PWRKEY)
unnamed: C7.1, X2.3 (SIGNAL)
unnamed: Q1.3 (D), R5.1
unnamed: LED2.C, R5.2
unnamed: J4.5, JP1.1
unnamed: J4.1, JP2.1
unnamed: Q2.3 (D), R8.1
unnamed: LED3.C, R8.2
unnamed: JP3.2, LED2.A
unnamed: LED1.A, R1.2
NETLIGHT: Q2.1 (G), U1.52 (NETLIGHT)
NRESET: D2.A, U1.16 (NRESET)
PROG: IC1.5 (PROG), R2.1
PWR_STAT: Q1.1 (G), U1.66 (STATUS)
RF_ANT: U1.60 (RF_ANT), X1.3 (SIGNAL)
SCL: IC3.2 (SCL), J3.1, J4.10, R4.1
SDA: IC3.1 (SDA), J3.2, J4.9, R6.1
SIM_CLK: D3.3 (2), U1.32 (SIM_CLK), X3.C3
SIM_DATA: D3.5 (4), U1.31 (SIM_DATA), X3.C7
SIM_RST: D3.4 (3), U1.33 (SIM_RST), X3.C2
SIM_VCC: C6.1, D3.1, U1.30 (SIM_VDD), X3.C1
STAT: IC1.1 (STAT), R1.1
UC_DTR: IC2.10 (B4), JP2.2
UC_RI: IC2.11 (B3), J4.2
UC_RXD: IC2.12 (B2), J4.3
UC_TXD: IC2.13 (B1), J4.4
VCC: C4.1, C5.1, IC2.14 (VCCB), IC3.8 (VDD), J3.4, JP4.2, R3.2, R4.2, R6.2
VIN: C2.1, C8.1, C9.1, C10.1, C11.1, C12.1, IC1.3 (VBAT), J1.8, J6.2 (1), JP3.1, LED3.A, U1.55 (VBAT), U1.56 (VBAT), U1.57 (VBAT)
V_LOGIC: J7.2, JP4.1
V_USB: J8.VBUS, U1.24 (USB_VBUS)

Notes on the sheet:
IOREF
3.3V
RESET
GND
VIN
0->RX
1<-TX
AREF
SDA
SCL
Timothy Woo
CC-BY-SA-4.0
SIM7000 / micro USB / SIM Card Interface
Headers and Pinouts
LiPo Battery Charging
I2C Temperature Sensor
ADDR: 0x18
UART Logic Level Shifting
VBAT
SIM7000 Status LEDs
Cut jumper to disable PWR LED
Power Down Mode: Negligible (off) Power Saving Mode: 9uA GNSS: 30mA (tracking), 6mA (DPO) GPRS: Up to 425mA EDGE: Up to 425mA LTE: ~150mA (23dBm) LTE Sleep: ~1mA LTE Idle: ~11mA
NOTE: The Arduino will likely draw a lot more current than the LTE shield. If you are concerned about low power, please select or design a board wisely!
Extra I2C header
Bridge jumper to connect DTR pin
Bridge jumper to connect ALERT pin
Operating current: 200uA Shutdown current: 0.1uA
MCU logic voltage (1.8V - 5.5V)
5V logic by default. Cut trace and bridge jumper for other logic voltages
Set for 500mA charging
10K = 100mA
5.0K = 200mA
2.0K = 500mA
PROG Resistor Val:
VBAT is the same as the LiPo battery voltage and SIM7000 power supply

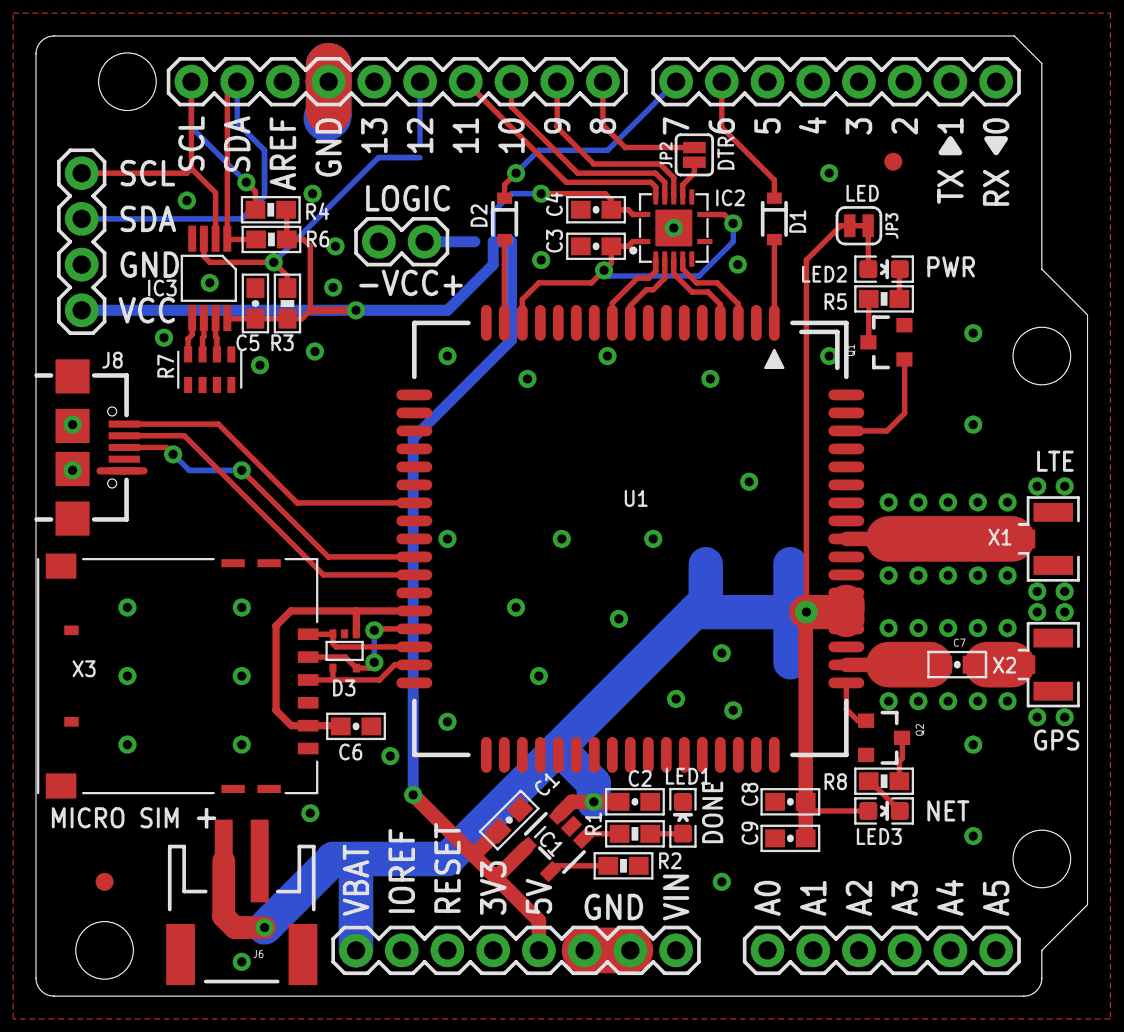
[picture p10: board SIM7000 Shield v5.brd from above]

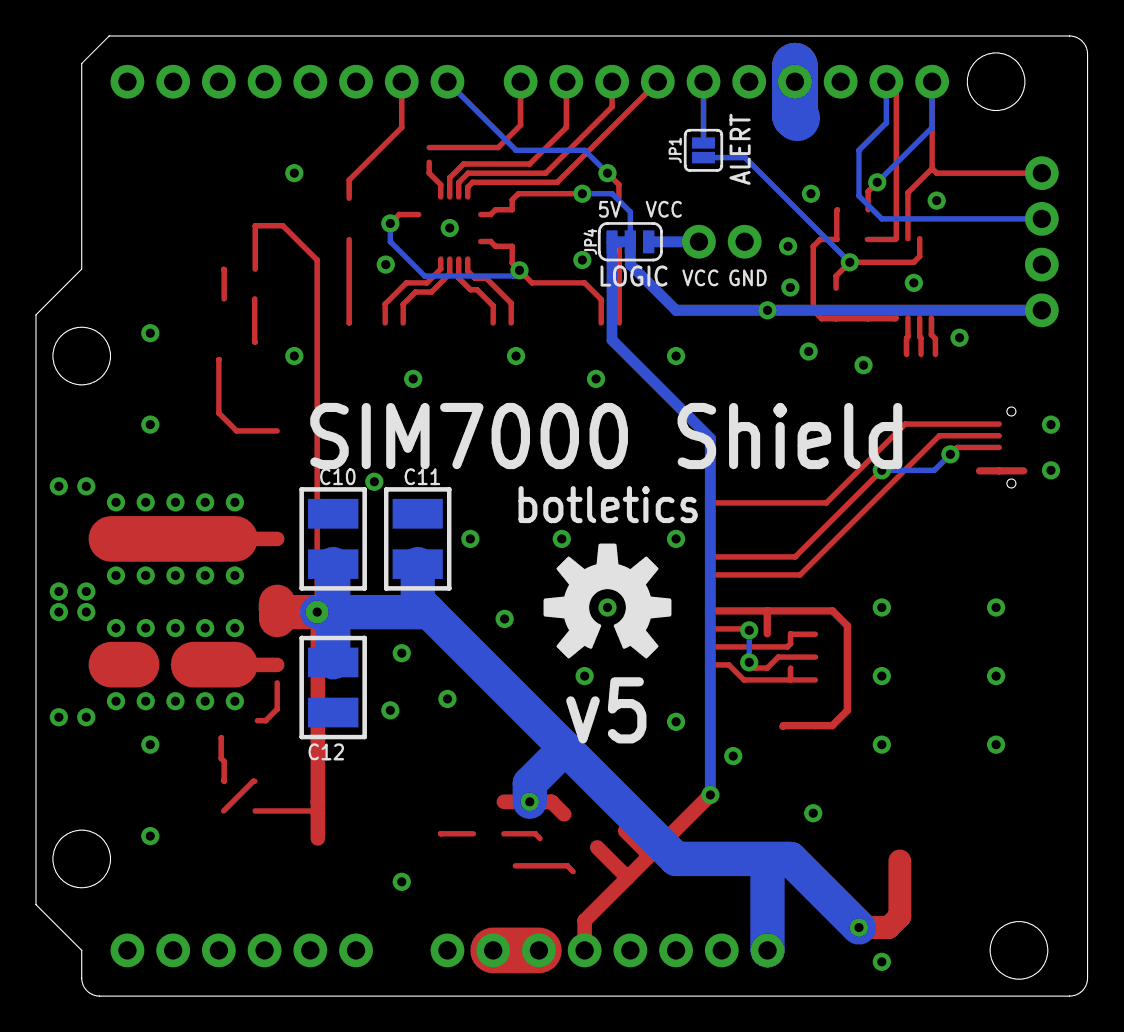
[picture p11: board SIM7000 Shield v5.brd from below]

Board: 2 copper layers, 58.4 x 53.3 mm, 50 parts (6 on the bottom side), 46 nets.

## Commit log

2017-11-09 Create LTE Shield v1.sch
    [LTE Shield v1.sch]
2017-11-09 Add files via upload
    I am aware that there is a slight bug with the PWR and NET LED's. This will be fixed in v2.
    [LTE Shield v1.brd, LTE Shield v1.sch]
2017-11-23 Create LTE Shield Schematic v3.pdf
2018-01-09 Enjoy open-source!
    [SIM7000 Shield v4.brd, SIM7000 Shield v4.sch]
2018-01-31 LiPo Support
    [SIM7000 Shield v5.brd, SIM7000 Shield v5.sch]
2018-03-08 Arduino Due support
2018-03-08 ARM support
2018-05-04 For SIM7000 and SIM7500
    Shortened to compile on Arduino Leonardo and exclude 2G/3G modules
2018-10-01 Optional SIM card PIN
2018-10-18 Changed serial port def for SAMD boards
2018-11-12 Added ESP8266 pin definitions
2018-12-07 Change sketch name serial printout
2019-07-22 Add battery topic
2019-07-22 Add MQTT functions
    - openWirelessConnection() function using AT+CNACT command
    - wirelessConnStatus() function using AT+CNACT?
    - MQTTsetParameter() function using AT+SMCONF
    - MQTTconnect() function using AT+SMCONN and AT+SMDISC
    - MQTTconnectionStatus() function using AT+SMSTATE?
    - MQTTsubscribe() function using AT+SMSUB
    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
2020-01-29 Comment out temp sensor wake line
2021-01-07 Add powerOn() function
2021-01-07 Use library powerOn() function
2021-01-07 Use library powerOn() function and add SIM7070
2021-01-27 Update Adafruit_FONA.cpp
    updated wirelessConnStatus() for SIM7070
2021-02-19 Fix powerOn() delay typo
2021-03-31 Fix power on logic
2021-04-10 Update Adafruit_FONA.cpp
    Some generic eBay boards seem to use a different revision / firmware of the 808 chip that is detected slightly differently - its still an 808 chip, but has the bluetooth and other bits enabled. I wil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
2021-06-13 Removing a warning/error. The sprintf function when %lu is specified expects a "long unsigned int" but the argument supplied was a uint32_t {aka unsugned int}. In this case the argument actually is a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
2021-06-13 Remove some warnings so that it's easier to see real issues when doing a build. Chunks of code are commented out when not doing specific things.
    If you don't care about UTC time all of the serial print statements are
    commented out but the declaration of the used variables are not commented
    out generating an un-needed warning.
    Likewise if you are not going to use the HTTP POST method to dweet.io the
    code is commented out but the declaration of the variable "body" is not
    commented out again generating an un-needed warning.
2022-01-28 Added method for checking SIM PIN requirement
2022-07-05 Fix temp sensor wake logic
2022-07-11 Fix for ESP32 compile

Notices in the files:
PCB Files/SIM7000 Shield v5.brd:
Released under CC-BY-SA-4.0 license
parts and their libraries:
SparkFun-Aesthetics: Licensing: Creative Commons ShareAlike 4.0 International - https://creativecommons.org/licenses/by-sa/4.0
